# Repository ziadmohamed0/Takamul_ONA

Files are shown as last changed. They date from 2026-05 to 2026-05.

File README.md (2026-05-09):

<div align="center">

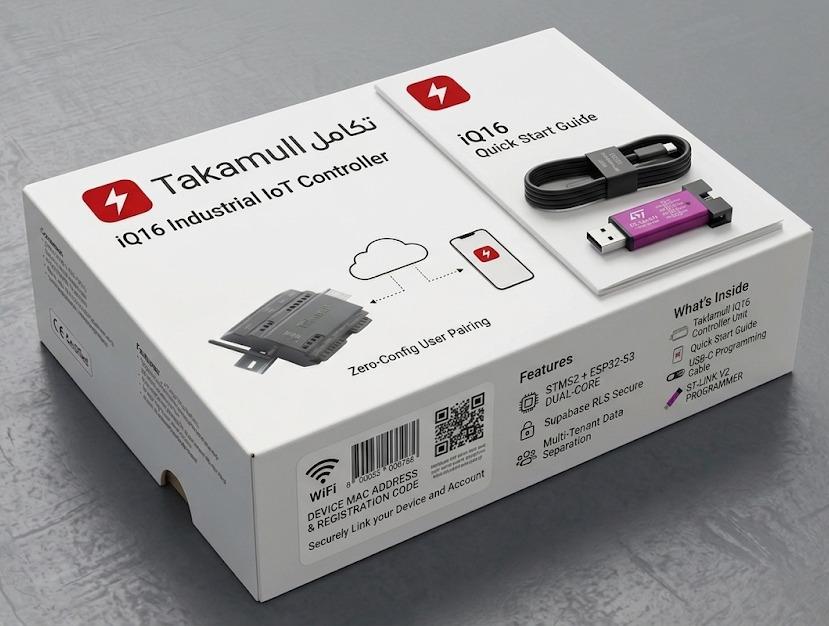
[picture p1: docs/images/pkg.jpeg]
Takamul iQ16 — Industrial IoT Controller


<br/>
<br/>

# Takamul iQ16 PLC

### Industrial IoT Controller — تكامل للحلول الذكية

<br/>








<br/>

> **Dual-core STM32F405 + ESP32-S3 · Supabase Multi-Tenant Cloud · Modbus RTU · DIN-Rail Mount**
> Designed for water treatment, flow control, and process automation in harsh industrial environments — engineered in Egypt 🇪🇬

</div>

---

## Table of Contents

- [Overview](#overview)
- [Key Features](#key-features)
- [System Architecture](#system-architecture)
- [Hardware](#hardware)
  - [PCB](#pcb--ona_hard)
  - [Mechanical Enclosure — V1](#mechanical-enclosure--v1)
  - [Mechanical Enclosure — V2](#mechanical-enclosure--v2)
- [Firmware](#firmware)
- [Cloud & Connectivity](#cloud--connectivity)
- [Repository Structure](#repository-structure)
- [Getting Started](#getting-started)
- [Supported Instruments](#supported-instruments)

---

## Overview

The **Takamul iQ16** is a compact, DIN-rail mounted industrial PLC built for real-world process automation. It pairs a **STM32F405RGT6** real-time controller — handling deterministic Modbus RTU field communication — with an **ESP32-S3** managing Wi-Fi, MQTT, and secure cloud telemetry via **Supabase Row-Level Security**.

Every unit ships ready to deploy: scan the MAC QR code on the box, link it to your account, and the device self-configures with zero manual setup.

**Built for:**
- Water treatment & desalination plants
- Flow metering systems (Endress+Hauser Promag P300)
- Multi-parameter water quality monitoring (TDS, pressure, temperature, differential)
- VFD pump control automation

---

## Key Features

| | Feature | Detail |
|---|---|---|
| ⚙️ | **Dual-Core Processing** | STM32F405RGT6 (real-time control) + ESP32-S3 (connectivity) |
| 📡 | **Field Protocols** | Modbus RTU × 2 ports (RS-485), bridged to cloud via MQTT |
| 🌊 | **Sensor Inputs** | Flow · Pressure · TDS · Temperature · Differential (5 channels) |
| ⚡ | **Actuator Outputs** | VFD Control × 2 (Variable Frequency Drive) |
| 🔋 | **Power Supply** | 12–24V DC wide-range input, onboard LM2596S regulator |
| 📶 | **Connectivity** | Wi-Fi 802.11 b/g/n, external SMA antenna, USB-C programming |
| ☁️ | **Cloud Backend** | Supabase PostgreSQL + RLS — multi-tenant, per-device data isolation |
| 🔐 | **Security** | JWT auth, RLS policies, NVS encrypted credential storage |
| 💡 | **Status Indicators** | Power · Run · Error · Comms · Wi-Fi (5 onboard LEDs) |
| 📦 | **Form Factor** | DIN-rail 35mm TS35, 3D-printable enclosure included |
| 🔌 | **Programming** | ST-LINK V2 (STM32) + USB-C ESP-IDF (ESP32) |
| 📋 | **Zero-Config** | MAC-based QR pairing — no manual IP or credential entry |

---

## System Architecture

```
┌─────────────────────────────────────────────────────────┐
│                    Field Instruments                     │
│  [Flow Meter]  [Pressure]  [TDS]  [Temp]  [Diff]       │
└──────────────────────┬──────────────────────────────────┘
                       │ Modbus RTU (RS-485)
              ┌────────▼────────┐
              │   STM32F405     │  ← Real-time deterministic control
              │  Modbus Master  │  ← VFD pump output control
              │  FreeRTOS       │
              └────────┬────────┘
                       │ UART (115200 baud)
              ┌────────▼────────┐
              │    ESP32-S3     │  ← Wi-Fi / MQTT / Cloud
              │  WifiManager    │
              │  SupabaseClient │──────────► Supabase Cloud
              │  MqttManager    │              (PostgreSQL + RLS)
              │  TelemetryMgr   │
              │  WebServer      │──────────► Local Config Portal
              │  NVSManager     │
              └─────────────────┘
```

---

## Hardware

### PCB — `ONA_HARD/`

The iQ16 PCB is a **4-layer board** designed in KiCad 7. The stackup separates power planes from signal layers to ensure clean analog sensor readings alongside noisy RS-485 and switching regulator circuits.

| Spec | Value |
|---|---|
| Layers | 4 (F.Cu · In1.Cu · In2.Cu · B.Cu) |
| MCUs | STM32F405RGT6 + ESP32-S3 module |
| Power | LM2596S buck converter, 220µF/35V + 100µF/50V bulk caps |
| RS-485 | Dual Modbus ports (ModBus 1: A/B, ModBus 2: Y/Z) |
| Programming | USB-C (ESP32) + ST-Link header (STM32) |
| Mounting | 4× M3 corner holes for DIN-rail clip assembly |
| Design tool | KiCad 7 |
| Fabrication | Gerber + drill files ready (JLCPCB / PCBWay) |

<table>
  <tr>
    <td align="center" width="50%">
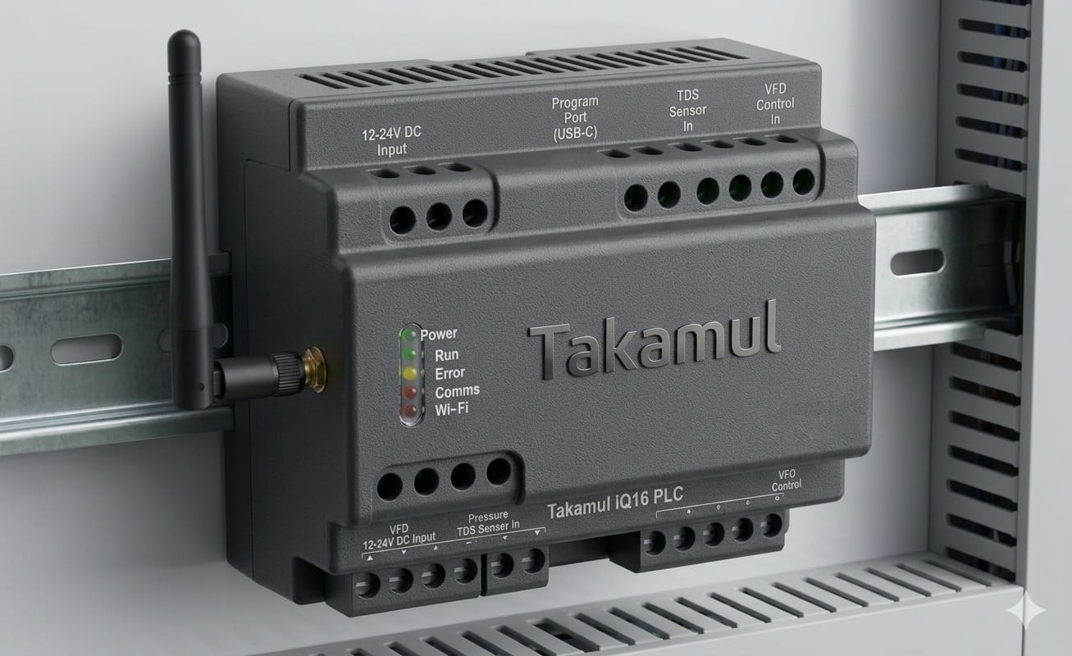
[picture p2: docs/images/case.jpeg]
iQ16 mounted on DIN rail
      
      <br/><sub><b>iQ16 — DIN-Rail Mounted</b></sub>
    </td>
    <td align="center" width="50%">
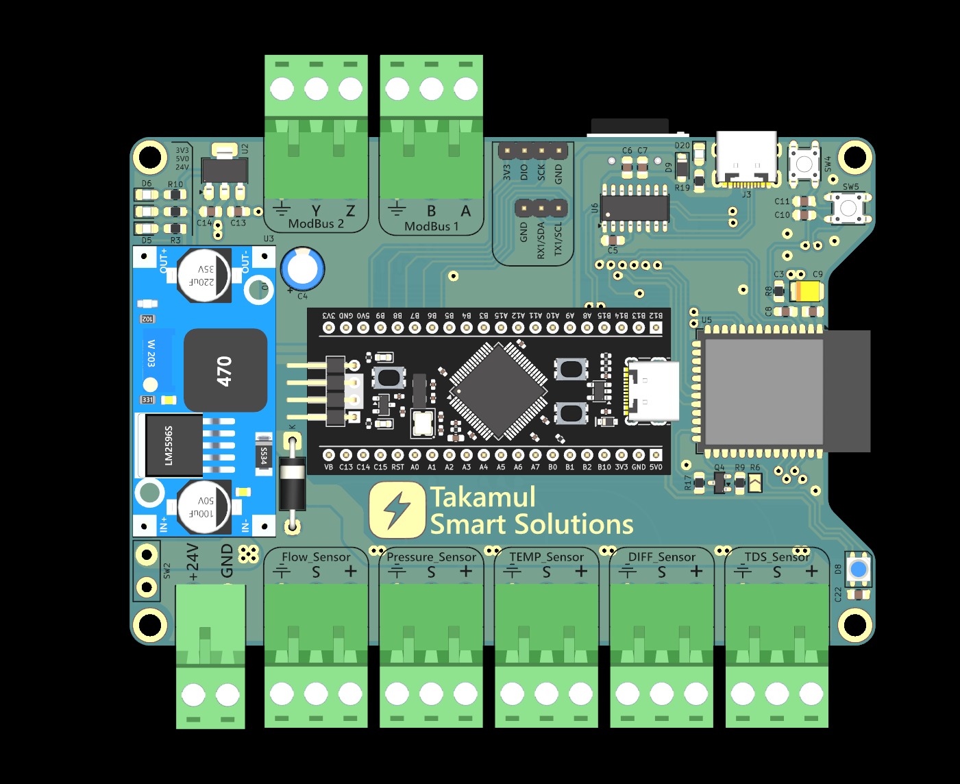
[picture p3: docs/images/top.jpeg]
PCB Top View
      
      <br/><sub><b>PCB — Top View (3D Render)</b></sub>
    </td>
  </tr>
  <tr>
    <td align="center" width="50%">
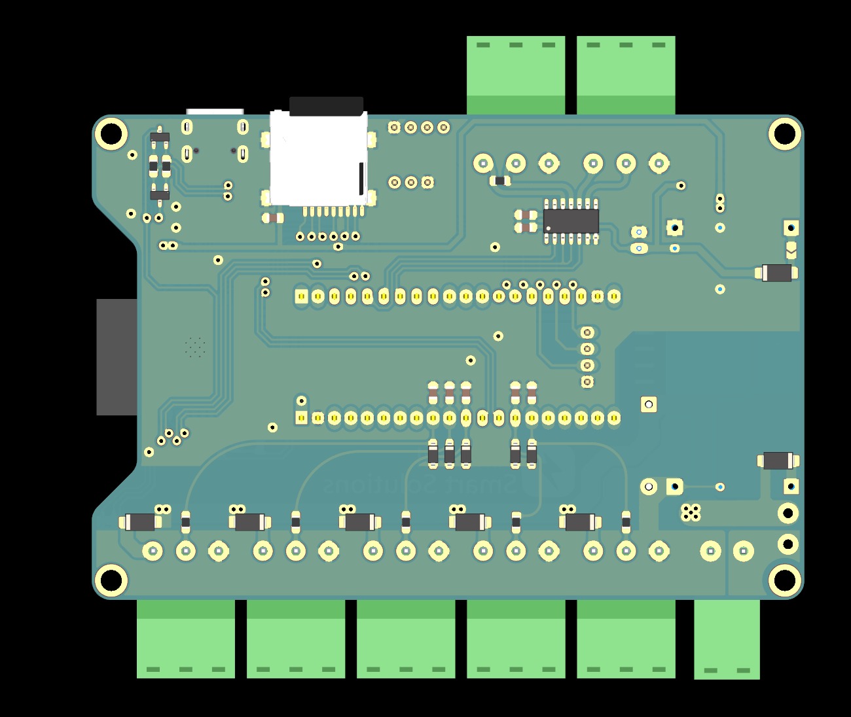
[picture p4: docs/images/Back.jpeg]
PCB Back View
      
      <br/><sub><b>PCB — Back View (3D Render)</b></sub>
    </td>
    <td align="center" width="50%">
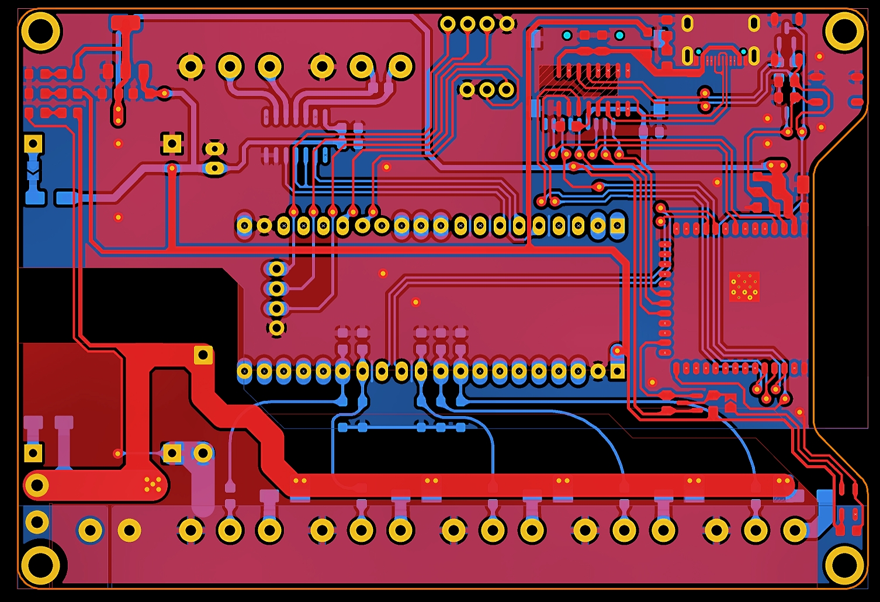
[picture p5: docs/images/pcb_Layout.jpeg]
PCB Layout
      
      <br/><sub><b>PCB — KiCad Layout (All Copper Layers)</b></sub>
    </td>
  </tr>
</table>

---

### Mechanical Enclosure — V1

First-generation 3D-printable enclosure. A 4-part snap-fit design tailored for DIN-rail deployment in standard control cabinets.

**Parts:** `Body` · `Face cover` · `Back cover` · `Head cover`

<table>
  <tr>
    <td align="center" width="50%">
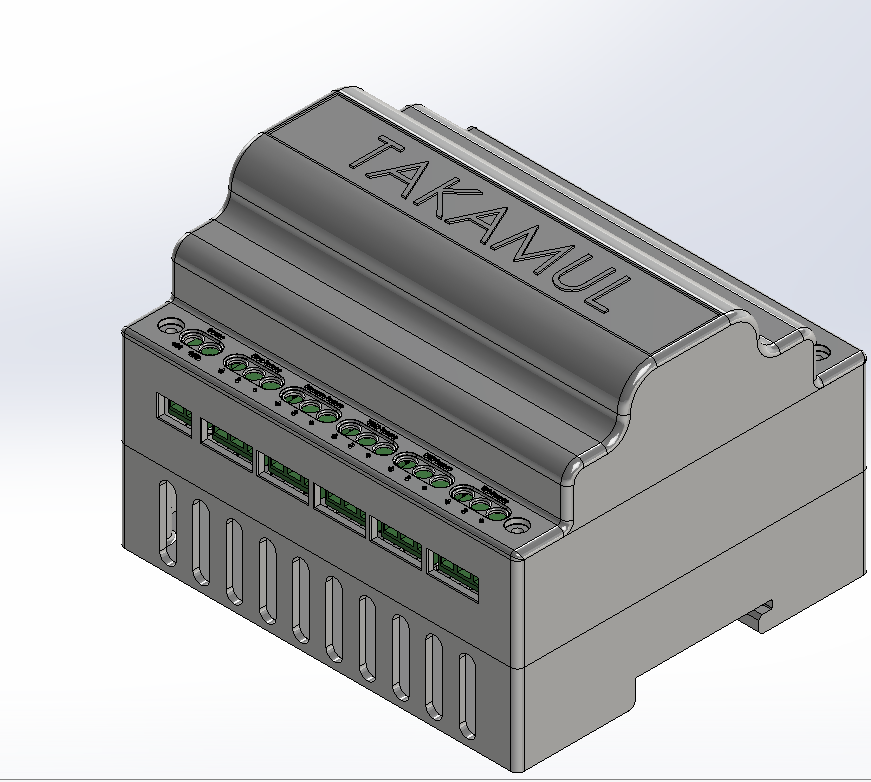
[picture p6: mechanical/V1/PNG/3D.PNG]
V1 3D View
      
      <br/><sub><b>V1 — Full Assembly (3D View)</b></sub>
    </td>
    <td align="center" width="50%">
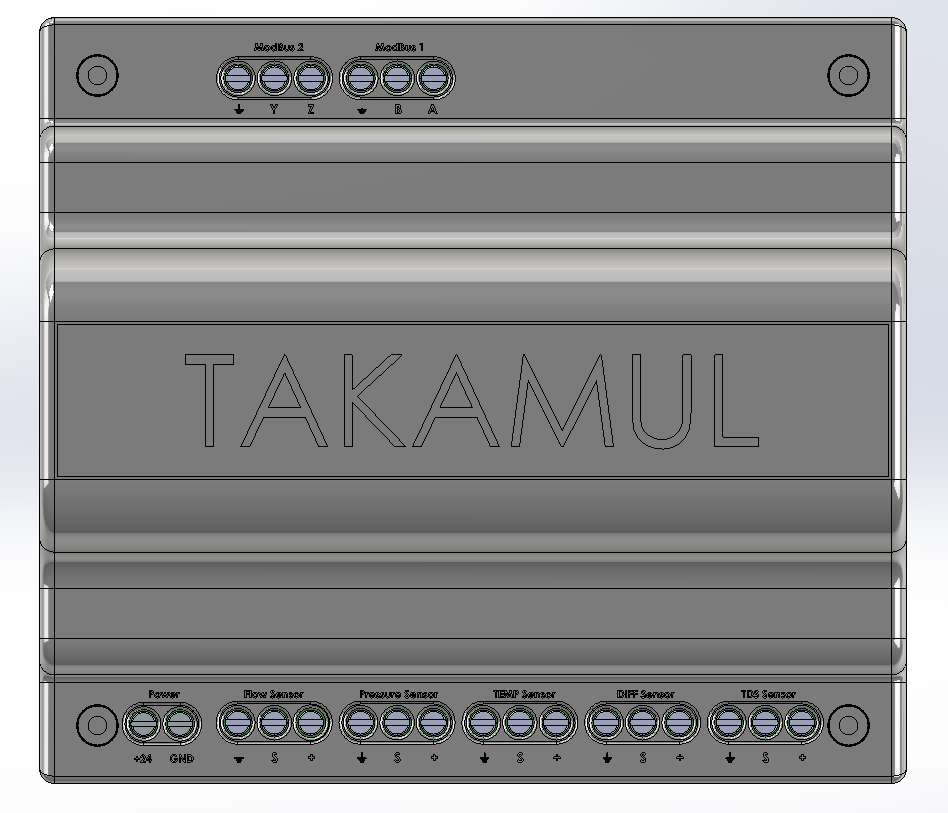
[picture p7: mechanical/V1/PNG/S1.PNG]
V1 Section 1
      
      <br/><sub><b>V1 — Front Panel View</b></sub>
    </td>
  </tr>
  <tr>
    <td align="center" width="50%">
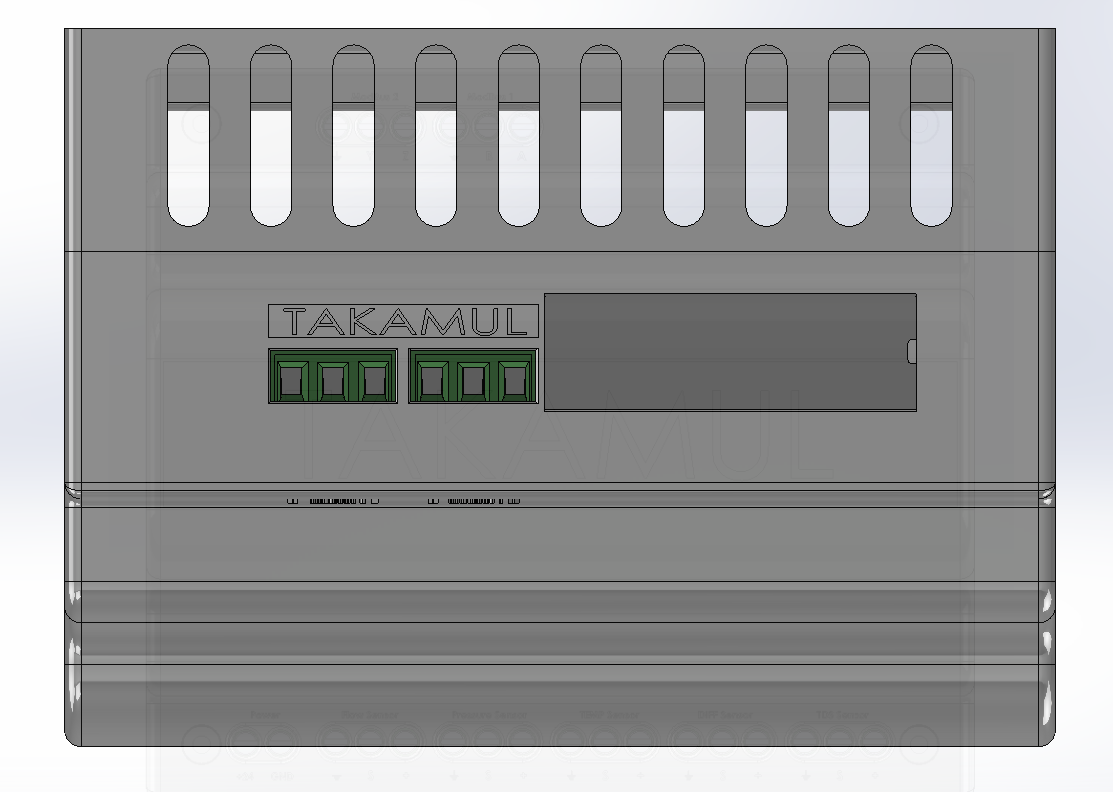
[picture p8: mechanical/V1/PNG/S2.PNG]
V1 Section 2
      
      <br/><sub><b>V1 — Side Profile</b></sub>
    </td>
    <td align="center" width="50%">
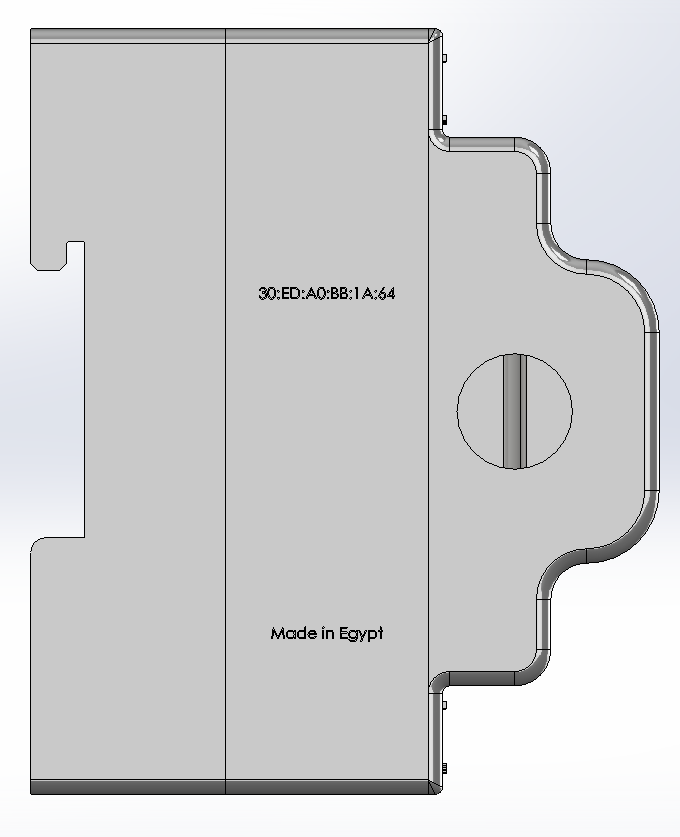
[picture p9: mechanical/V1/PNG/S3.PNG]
V1 Section 3
      
      <br/><sub><b>V1 — Internal Layout</b></sub>
    </td>
  </tr>
</table>

All V1 files are in `mechanical/V1/` — CAD source (`.SLDPRT` / `.SLDASM`) and print-ready STLs.

---

### Mechanical Enclosure — V2

Second-generation enclosure with improved cable management, refined connector cutouts, and a modular split body for easier PCB insertion and field service.

**Parts:** `Body` · `Face` · `Back` · `Part1348` (DIN clip assembly)

<table>
  <tr>
    <td align="center" width="50%">
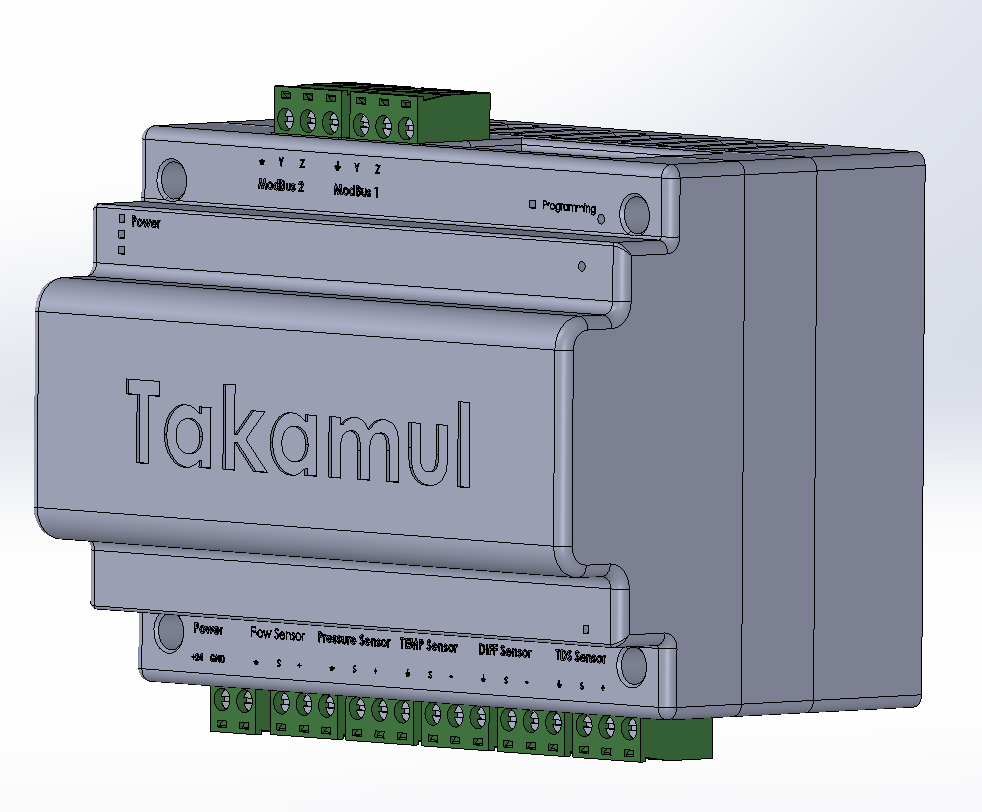
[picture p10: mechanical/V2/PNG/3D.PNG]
V2 3D View
      
      <br/><sub><b>V2 — Full Assembly (3D View)</b></sub>
    </td>
    <td align="center" width="50%">
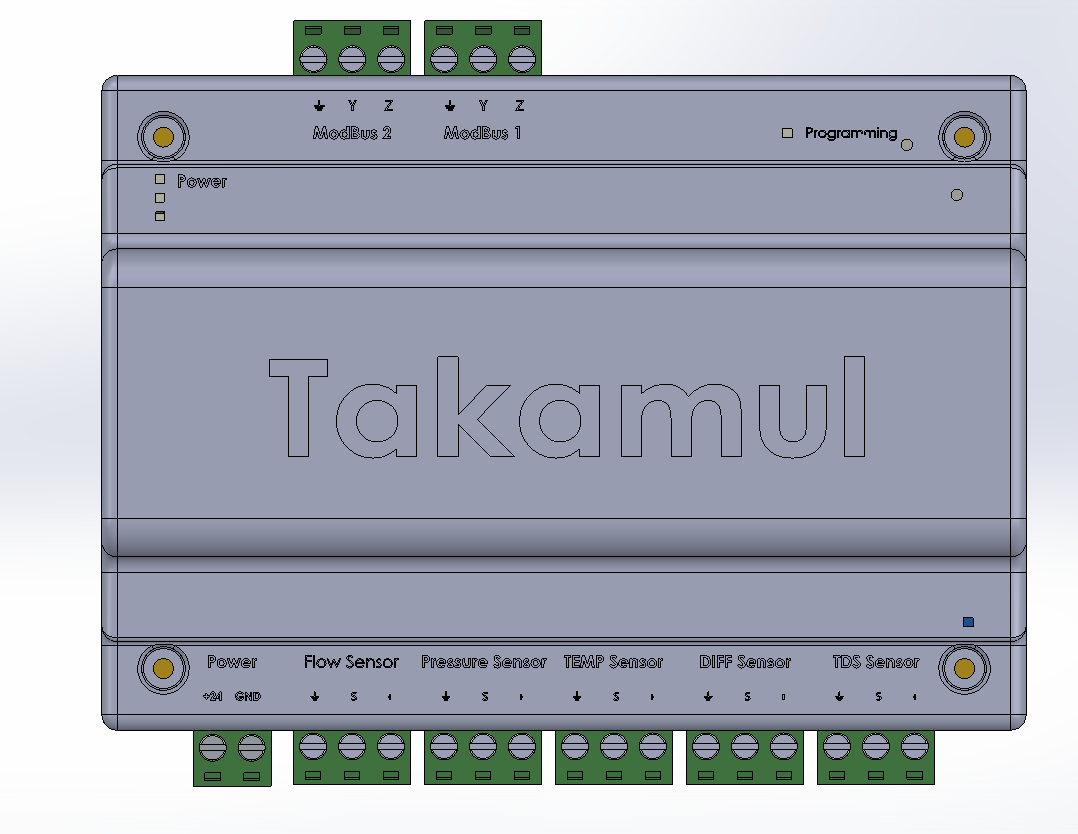
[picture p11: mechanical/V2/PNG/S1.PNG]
V2 Section 1
      
      <br/><sub><b>V2 — Front Panel View</b></sub>
    </td>
  </tr>
  <tr>
    <td align="center" width="50%">
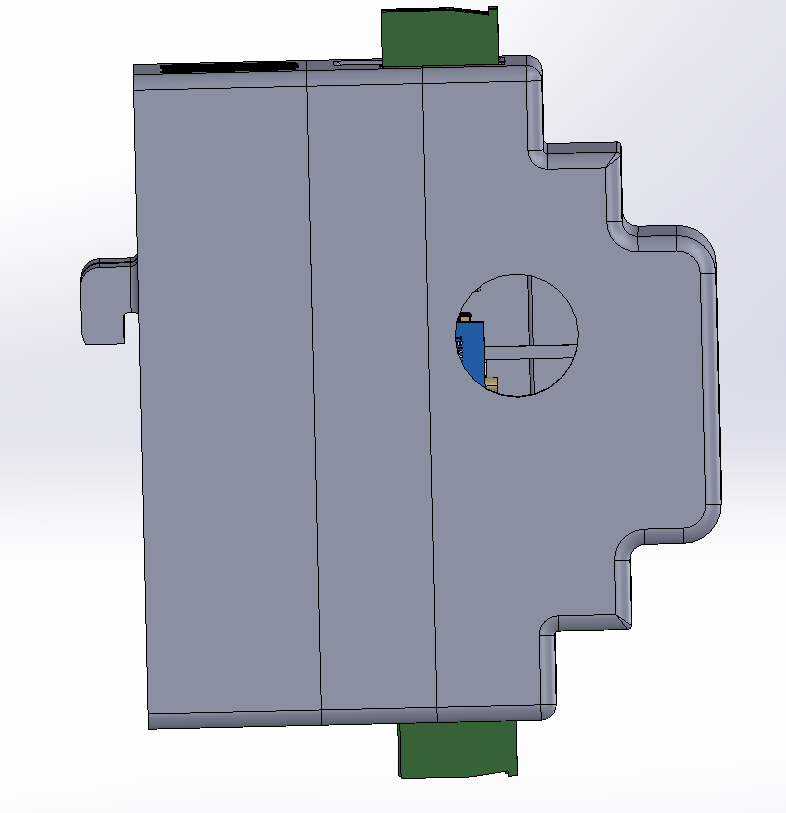
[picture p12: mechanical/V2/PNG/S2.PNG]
V2 Section 2
      
      <br/><sub><b>V2 — Side Profile</b></sub>
    </td>
    <td align="center" width="50%">
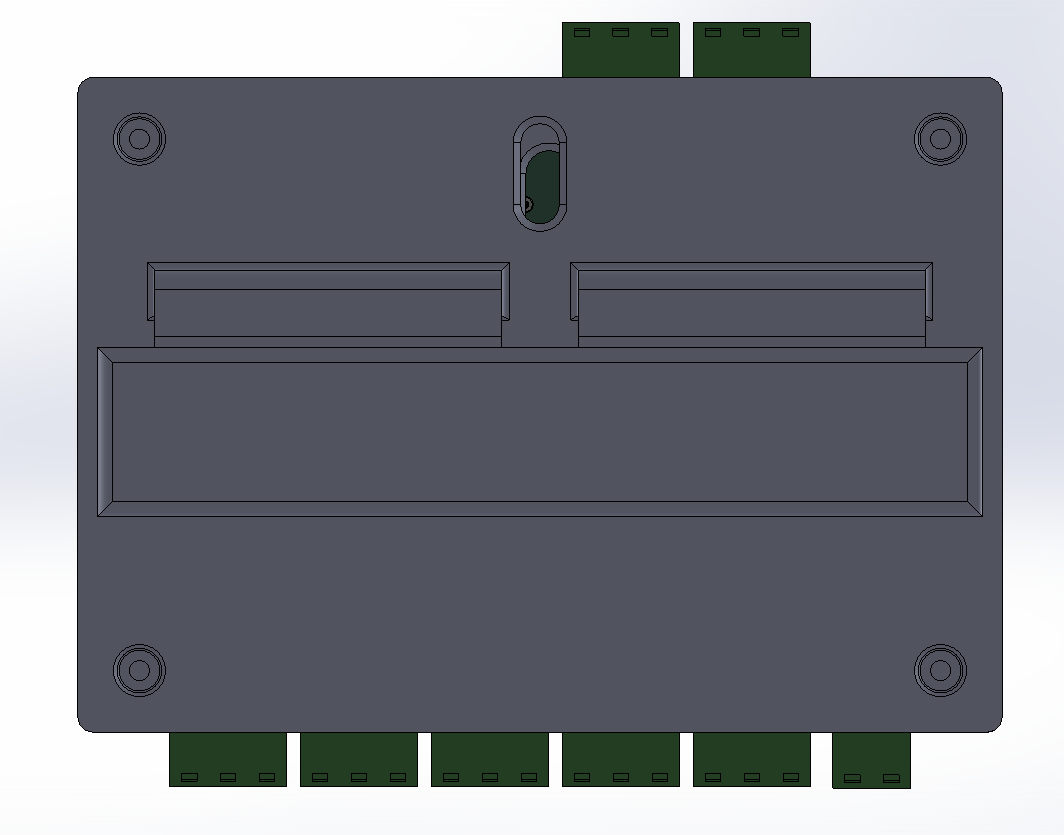
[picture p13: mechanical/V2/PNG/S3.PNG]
V2 Section 3
      
      <br/><sub><b>V2 — Rear Connector Cutouts</b></sub>
    </td>
  </tr>
  <tr>
    <td align="center" colspan="2">
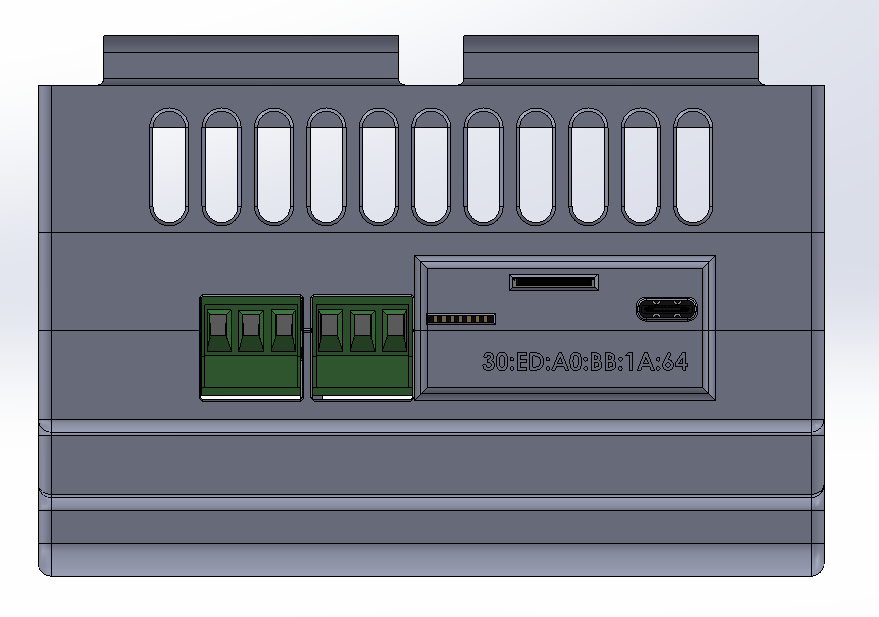
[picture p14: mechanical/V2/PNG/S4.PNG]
V2 Section 4
      
      <br/><sub><b>V2 — Exploded View / DIN Clip Detail</b></sub>
    </td>
  </tr>
</table>

All V2 files are in `mechanical/V2/` — CAD source and print-ready STLs.

> **Production-ready STL + OBJ** files (the version shipped with the product) are in `mechanical/sample/cad_v2/`. These include every printable part: `assembly`, `base`, `front_lid`, `top_lid`, `top_connectors`, `bottom_connectors`, `din_clip`, `wifi_module`, `antenna`, `standoff`, `screw_m3x8`.

---

## Firmware

### ESP32-S3 — `ONA_Software/software_v1/` (ESP-IDF v5)

The ESP32 owns all network and cloud operations, acting as a transparent bridge between the STM32 field data and the Supabase backend.

```
Takamul:: namespace
│
├── NVSManager        Flash-backed credential & config storage
├── WifiManager       Auto-connect, reconnect, provisioning fallback
├── SupabaseClient    HTTPS REST client — insert/query with JWT RLS auth
├── TelemetryManager  Periodic sensor data batching & upload
├── MqttManager       Real-time bidirectional command channel
├── UartBridge        UART2 ↔ STM32 framing & protocol (GPIO 16/17)
├── WebServer         Local HTTP config portal for Zero-Config pairing
├── OtaManager        OTA firmware update over HTTPS
└── SleepManager      Deep-sleep power management
```

**Configuring credentials** (via `idf.py menuconfig → Takamul Config`):

```
CONFIG_TAKAMUL_SUPABASE_URL   → your Supabase project URL
CONFIG_TAKAMUL_SUPABASE_KEY   → your anon/service role key
```

### STM32F405 — `ONA_Software/tests/modbus_v2/` (STM32CubeIDE)

Runs a deterministic FreeRTOS Modbus RTU master stack over RS-485. Polls all field instruments on configurable scan cycles and pushes structured telemetry frames to the ESP32 over UART.

### Modbus Mapping — `ONA_Software/tests/modbus_mapping_controll/`

STM32 firmware variant with full register mapping and VFD control logic — maps physical Modbus registers from flow meters, TDS analyzers, and pressure transmitters to structured data objects sent upstream.

---

## Cloud & Connectivity

| Layer | Technology | Purpose |
|---|---|---|
| **Database** | Supabase PostgreSQL | Persistent sensor telemetry & device registry |
| **Security** | Row-Level Security (RLS) | Per-device data isolation, multi-tenant safe |
| **Auth** | JWT tokens | Device identity tied to MAC address |
| **Real-time** | Supabase Realtime | Live dashboard subscriptions |
| **Commands** | MQTT pub/sub | Low-latency actuator control (VFD setpoints) |
| **Local config** | HTTP Web Server | Zero-Config Wi-Fi & account pairing |
| **Pairing** | QR code on box | MAC address → account link, no manual entry |
| **OTA** | HTTPS OTA | Remote firmware updates for ESP32 |

---

## Repository Structure

```
Takamul_ONA/
│
├── ONA_HARD/                          # Hardware design files
│   ├── STM32 & ESP32.kicad_pro       # KiCad 7 project
│   ├── STM32 & ESP32.kicad_sch       # Schematic
│   ├── STM32 & ESP32.kicad_pcb       # PCB layout
│   ├── BOM.xlsx                       # Bill of Materials
│   ├── STM32 & ESP32.pdf             # Schematic PDF export
│   ├── STEP File.step                 # Full assembly STEP
│   ├── top.jpeg / Back.jpeg          # PCB 3D renders
│   └── pcb_Layout.jpeg               # KiCad layout screenshot
│
├── ONA_Software/
│   ├── software_v1/esp32s3_project/  # ESP32-S3 firmware (ESP-IDF v5)
│   │   └── main/
│   │       ├── main.cpp / main.h
│   │       ├── src/
│   │       │   ├── WifiManager.cpp
│   │       │   ├── SupabaseClient.cpp
│   │       │   ├── TelemetryManager.cpp
│   │       │   ├── UartBridge.cpp
│   │       │   ├── WebServer.cpp
│   │       │   ├── MqttManager.cpp
│   │       │   ├── NVSManager.cpp
│   │       │   ├── OtaManager.cpp
│   │       │   └── SleepManager.cpp
│   │       └── inc/                  # Corresponding headers
│   │
│   ├── tests/
│   │   ├── modbus_v2/               # STM32F405 Modbus RTU stack (FreeRTOS)
│   │   ├── modbus_mapping_controll/ # Register mapping & VFD control logic
│   │   ├── STM32_Main/              # STM32F401 base firmware tests
│   │   ├── TestModbus/              # Modbus protocol unit tests
│   │   ├── stm32_master/            # STM32F103 Modbus master prototype
│   │   ├── main_esp32/              # ESP32 (original) integration tests
│   │   └── test_db/                 # ESP32 Supabase integration tests
│   │
│   └── data_sheets/                 # Instrument Modbus documentation
│       ├── Promag_P300_modbus_map.pdf
│       └── CM44x_modbus_map.pdf
│
├── mechanical/
│   ├── V1/                          # Enclosure V1 (SolidWorks + STL)
│   │   ├── CAD/                     # .SLDPRT source files
│   │   ├── STL/                     # Print-ready STL files
│   │   └── PNG/                     # 3D renders (3D, S1, S2, S3)
│   │
│   ├── V2/                          # Enclosure V2 (SolidWorks + STL)
│   │   ├── CAD/                     # .SLDPRT source files
│   │   ├── STL/                     # Print-ready STL files
│   │   └── PNG/                     # 3D renders (3D, S1, S2, S3, S4)
│   │
│   └── sample/                      # Production-ready assets
│       ├── cad_v2/                  # Final STL + OBJ (all parts)
│       ├── docs/
│       │   ├── bom_v2.csv
│       │   └── takamul_iq16_drawing_pack.pdf
│       ├── case.jpeg                # Mounted enclosure photo
│       └── pkg.jpeg                 # Product packaging render
│
└── docs/
    └── images/                      # README assets
```

---

## Getting Started

### What's in the Box

- Takamul iQ16 Controller Unit
- Quick Start Guide
- USB-C Programming Cable
- ST-LINK V2 Programmer

### Prerequisites

| Tool | Purpose | Link |
|---|---|---|
| ESP-IDF v5 | ESP32-S3 firmware build | [docs.espressif.com](https://docs.espressif.com/projects/esp-idf/en/latest/) |
| STM32CubeIDE | STM32 firmware build & flash | [st.com](https://www.st.com/en/development-tools/stm32cubeide.html) |
| KiCad 7 | PCB schematic & layout | [kicad.org](https://www.kicad.org) |
| ST-LINK V2 | STM32 programmer (included) | — |

### Flash ESP32 Firmware

```bash
cd ONA_Software/software_v1/esp32s3_project
idf.py set-target esp32s3
idf.py menuconfig        # Takamul Config → set Supabase URL & key
idf.py build flash monitor
```

### Flash STM32 Firmware

```bash
# Open in STM32CubeIDE
File → Open Projects from File System → ONA_Software/tests/modbus_v2/

# Build & flash via ST-LINK V2
Project → Build (Ctrl+B)
Run → Debug (connects via ST-LINK header)
```

### Open PCB in KiCad

```bash
kicad ONA_HARD/
# Open "STM32 & ESP32.kicad_pro" → Schematic Editor or PCB Editor
```

### Print the Enclosure (V2 — Production)

All production STL files are in `mechanical/sample/cad_v2/`. Recommended print order:

1. `base.stl` — main enclosure body
2. `din_clip.stl` — DIN-rail clip
3. `front_lid.stl` — front panel
4. `top_lid.stl` — top cover
5. `top_connectors.stl` + `bottom_connectors.stl` — terminal cutout panels
6. `standoff.stl` × 4 — PCB standoffs
7. `wifi_module.stl` — ESP32 module retainer
8. `antenna.stl` — SMA antenna bracket

> **Recommended settings:** PLA or PETG, 0.2mm layer height, 4 perimeters, 30% infill.

---

## Supported Instruments

| Instrument | Protocol | Datasheet |
|---|---|---|
| Endress+Hauser Promag P300 | Modbus RTU | `ONA_Software/data_sheets/Promag_P300_modbus_map.pdf` |
| Endress+Hauser Liquiline CM44x | Modbus RTU | `ONA_Software/data_sheets/CM44x_modbus_map.pdf` |
| Generic TDS Sensor | Analog / RS-485 | — |
| Generic Pressure Transmitter | 4–20 mA | — |
| Generic Temperature Sensor | Analog | — |

---

<div align="center">

<br/>

**Takamul Smart Solutions — تكامل للحلول الذكية**

*Industrial IoT, engineered in Egypt 🇪🇬*

<br/>

</div>

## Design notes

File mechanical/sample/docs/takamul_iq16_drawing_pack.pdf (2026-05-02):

# Takamul IQ16 PLC - Reverse Engineered Package

Reference-based 3D/STL/OBJ package derived from supplied images

### Package contents:

- STL and OBJ files for base, front lid, top vent lid, antenna, DIN clip, screw, standoff, full assembly

### - PDF drawing pack and source SCAD - Included reference images used for reverse engineering

### Primary dimensions used:

160 mm width, 115 mm height, 62 mm depth, 2.5 mm wall thickness,
140 mm top module width, 95 mm body span noted in sheet, M3x8 screws, ABS / metal material note.

### Important note:

Several internal/detail dimensions are not fully readable in the supplied sheet.
Those areas were reconstructed as manufacturable approximations while preserving the visible external envelope and named features.

# Orthographic Control Dimensions

External envelope and major visible interface groups

Takamul

160 mm

115 mm

55 mm 20 mm 55 mm
FRONT VIEW

62 mm

115 mm

SIDE VIEW

140 mm

62 mm

TOP VIEW

# Internal Features and Assembly Notes

Reconstructed from exploded views and labels visible in the supplied sheet

Item | Count | Material/Type | Notes
Housing base | 1 | ABS-like shell | 160 x 62 x 115 mm external envelope; 2.5 mm nominal wall
Front lid | 1 | ABS-like shell | Front plate and terminal shelves
Top vent lid | 1 | ABS-like shell | Approx. 140 mm wide vent cover
Antenna | 1 | Plastic/rubber visual modelSeparate simplified external antenna
DIN rail clip | 1 | Spring metal simplified | Rear mounting clip placeholder
PCB mounting bosses | 6 | Integrated plastic | Internal posts with pilot holes
Connector bosses | 6 | Integrated plastic | Near terminal regions
Screw posts | 4 | Integrated plastic | Corner posts for enclosure fastening
Brass standoffs | 4 | Brass simplified | M3-compatible
Brass M3 x 8 screws | 4 | Metal simplified | Visual/assembly placeholders
USB-C holder | 1 | Integrated plastic | Bottom-center slot/holder region
Wi-Fi bracket/routing | 1 | Integrated plastic | Internal routing guide / bracket

Assumptions used where the sheet is incomplete: terminal-hole pitch, detailed boss spacing, DIN clip geometry, antenna boss shape, and exact cover split line. These were reconstructed to preserve the visible layout and create a workable manufacturing/printing package.

# Reference Images Included

Supplied by the user and packed inside the ZIP under /refs

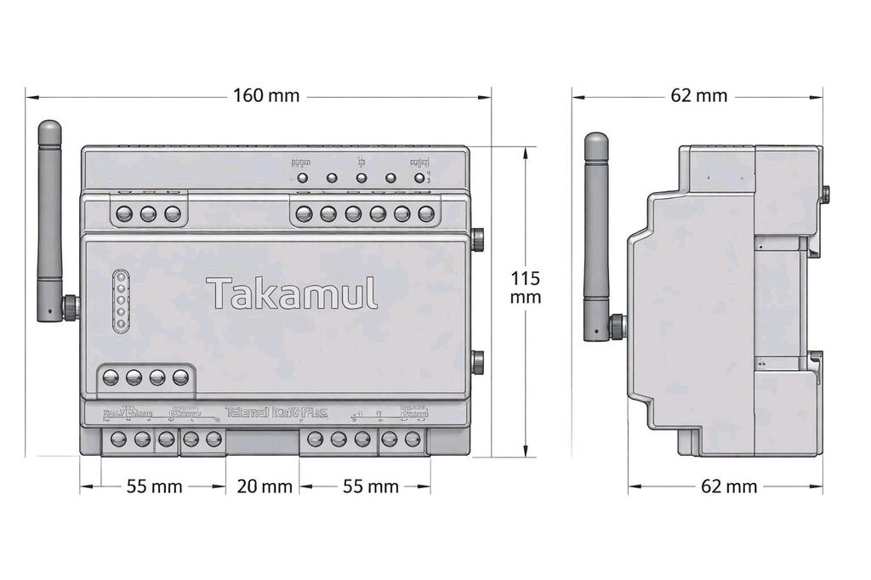
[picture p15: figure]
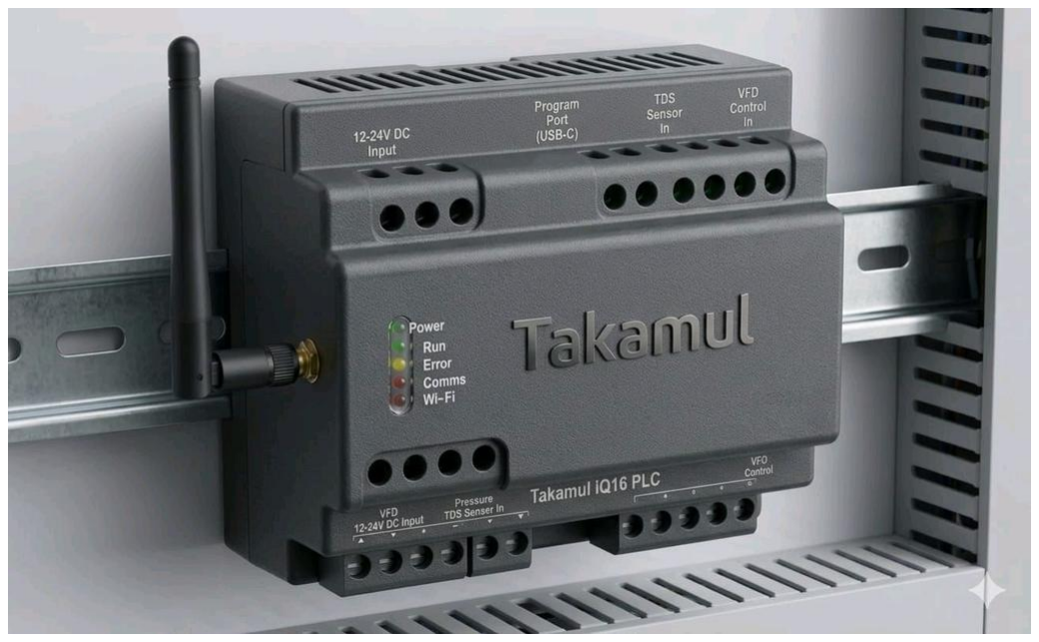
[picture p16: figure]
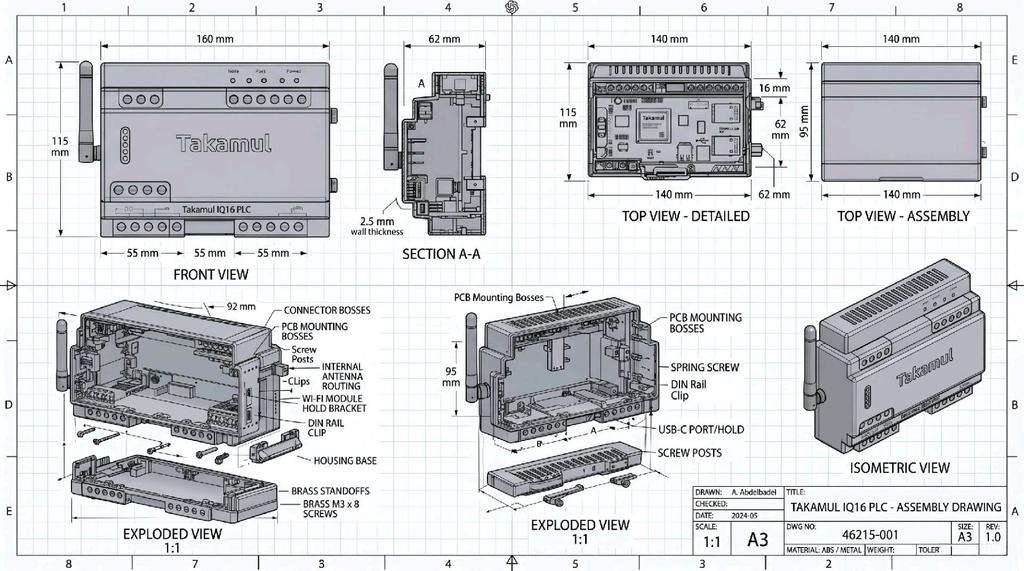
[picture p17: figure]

assembly_sheet.jpg | product_render.jpg | dimension_views.jpg

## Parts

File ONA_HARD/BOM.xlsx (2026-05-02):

Ref | Value | Footpint | Qty | Shop | Link
C14 | 22U | Capacitor_SMD:C_0805_2012Metric_Pad1.18x1.45mm_HandSolder | 1 | Makers | https://makerselectronics.com/product/multilayer-ceramic-capacitors-mlcc-smd-25v-22uf-x5r-%c2%b120-0805/
D2, D15-D19 | SS36 | Diode_SMD:D_SMA | 6 | Makers | https://makerselectronics.com/product/ss36-sma-schottky-barrier-diodes-sbd-smd-60v-single-0-7v3a-3a/
D3 | SS16 | Diode_SMD:D_SMA | 1 | Makers | https://makerselectronics.com/product/ss16-sma-schottky-barrier-diodes-sbd-smd-60v-700mv1a-1a/
D4 | P6KE27A | Diode_THT:D_DO-15_P12.70mm_Horizontal | 1 | Makers | https://makerselectronics.com/product/esd-suppressors-tvs-diodes-600w-27v-uni-directional-p6ke27a-e3-73/
D5, D6, D10 | LED_RED | LED_SMD:LED_0805_2012Metric_Pad1.15x1.40mm_HandSolder | 3 | Makers | https://makerselectronics.com/product/smd-led-0805/
D7, D11-D14 | MM1Z3V3 | Diode_SMD:D_SOD-123 | 5 | Makers | https://makerselectronics.com/product/mm1z3v3-w3-zener-diode-smd-single-3-1v3-5v-500mw-3-3v-sod-123/
D9 | 1N5819WF | Diode_SMD:D_SOD-123F | 1 | Makers | https://makerselectronics.com/product/1n5819wf-sl-40v-600mv1a-1a-smd-sod-123f-smd-schottky-barrier-diodes-sbd/
J2 | Pluggable Terminal 2P | abjad:Pluggable Terminal 2P P5.08mm | 1 | Makers | https://makerselectronics.com/product/terminal-block-kf2edgr-5-08-2p/
J3 | USB_TYPEC_12P | Connector_USB:USB_C_Receptacle_G-Switch_GT-USB-7010ASV | 1 | Makers | https://makerselectronics.com/product/smd-usb-female-connectors-type-c-16-pin/
J4-J10 | Pluggable Terminal 3P | abjad:Pluggable Terminal 3P P5.08mm | 7 | Makers | https://makerselectronics.com/product/terminal-block-kf2edgr-5-08-3p/
J11 | UART | Connector_PinHeader_2.54mm:PinHeader_1x03_P2.54mm_Vertical | 1 | Makers | https://makerselectronics.com/product/pin-headers-male-2-54mm-40-pin-straight-black-11mm/
Q2, Q3 | SS8050 | Package_TO_SOT_SMD:SOT-23 | 2 | Makers | https://makerselectronics.com/product/ss8050-y1-bipolar-transistors-bjt-smd-25v-300mw-200100ma1v-1-5a-npn-sot-23/
R3 | 4K7 | Resistor_SMD:R_0805_2012Metric_Pad1.20x1.40mm_HandSolder | 1 | Makers | https://makerselectronics.com/product/chip-resistor-smd-4-7k%cf%89-%c2%b11-0-125w-%c2%b1100ppm-%e2%84%83-0805/
R4, R5, R8, R9, R17 | 10K | Resistor_SMD:R_0805_2012Metric_Pad1.20x1.40mm_HandSolder | 5 | Makers | https://makerselectronics.com/product/chip-resistor-smd-10k%cf%89-%c2%b15-0-125w-%c2%b1100ppm-%e2%84%83-0805/
R10 | 1K2 | Resistor_SMD:R_0805_2012Metric_Pad1.20x1.40mm_HandSolder | 1 | Makers | https://makerselectronics.com/product/chip-resistor-smd-1-2k%cf%89-%c2%b15-0-125w-%c2%b1100ppm-%e2%84%83-0805/
R11 | 2K2 | Resistor_SMD:R_0805_2012Metric_Pad1.20x1.40mm_HandSolder | 1 | Makers | https://makerselectronics.com/product/chip-resistor-smd-2-2k%cf%89-%c2%b11-0-125w-%c2%b1100ppm-%e2%84%83-0805/
R12-R16, R18 | 150R | Resistor_SMD:R_0805_2012Metric_Pad1.20x1.40mm_HandSolder | 6 | Makers | https://makerselectronics.com/product/chip-resistor-smd-150%cf%89-%c2%b11-0-125w-%c2%b1100ppm-%e2%84%83-0805/
SW2 | SW_6A | abjad:SW-KCD-6A | 1 | Makers | https://makerselectronics.com/product/on-off-red-switch-3-pins-250vac-6a/
U6 | CH340C | Package_SO:SOIC-16_3.9x9.9mm_P1.27mm | 1 | Makers | https://makerselectronics.com/product/ch340c-smd-ic-transceiver-usb-2-0-2mbps-sop-16/
U3 | LM2596S DC-DC | abjad:LM2596S DC-DC Converter 3A | 1 | Makers | https://makerselectronics.com/product/lm2596hvs-dc-dc-buck-converter-3a/
U4 | STM32F401RCT6 | abjad:Black Pill STM32F401RCT6 | 1 | Makers | https://makerselectronics.com/product/stm32f401rct6-stm32-development-boa/
U5 | ESP32-S3 N16R8 | RF_Module:ESP32-S3-WROOM-1 | 1 | Uge | https://uge-one.com/product/esp32-s3-n16r8-high-performance-wifi-ble5-smd-module/
U7 | MAX491E | Package_SO:SOIC-14_3.9x8.7mm_P1.27mm | 1 | Makers | https://makerselectronics.com/product/max491esd-transceiver-2-5mbps-1-1-soic-14-rs-485-rs-422-smd-ic/
J1 | SD Card Connector | abjad:SD Card Connector GCT_MEM2075 | 1 | UGE | https://uge-one.com/product/microsd-memory-sd-card-socket-pcb-mounted/
D8 | WS2812B | LED_SMD:LED_WS2812B-Mini_PLCC4_3.5x3.5mm | 1 | UGE | https://uge-one.com/product/ws2812b-programmable-rgb-led-chip-3535-smd-package/
Q4 | BSS138 | Package_TO_SOT_SMD:SOT-23 | 1 | Ram | https://www.ram-e-shop.com/shop/smd-bss138-smd-bss138-8694
SW4, SW5 | SW | Button_Switch_SMD:SW_SPST_PTS647_Sx50 | 2 | Uge | https://uge-one.com/product/smd-mini-pushbutton-switch-4p-4-5x4-5x2-5mm/
U2 | AMS1117-3.3 | Package_TO_SOT_SMD:SOT-223-3_TabPin2 | 1 | Ram | https://www.ram-e-shop.com/shop/lt1117-3-3v-ams1117-3-3v-6628

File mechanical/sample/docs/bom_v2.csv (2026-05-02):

item | count | material | category | notes
housing_base | 1 | ABS-like shell | enclosure | 2.5mm nominal wall based on drawing sheet
front_lid | 1 | ABS-like shell | enclosure | front cover with engraved logo and I/O labels
top_vent_lid | 1 | ABS-like shell | enclosure | 140mm visible top vented cover
antenna_whip | 1 | plastic/rubber | external | left-side antenna assembly with pivot base
din_clip | 1 | spring steel simplified | mechanical | rear DIN rail mount clip
main_pcb | 1 | FR4 simplified | electronics | placeholder board with major component envelopes
wifi_module | 1 | FR4 simplified | electronics | antenna-side daughter module placeholder
top_terminal_block_group | 1 | PA66/metal simplified | electronics | power + USB-C + sensor/VFD connector zone
bottom_terminal_block_group | 1 | PA66/metal simplified | electronics | lower DI/relay/RS485 connector zone
pcb_mounting_bosses | 6 | integrated plastic | integrated feature | internal PCB supports
connector_bosses | 11 | integrated plastic | integrated feature | front connector support features
screw_posts | 4 | integrated plastic | integrated feature | enclosure fastening towers
brass_standoffs | 4 | brass simplified | hardware | M3 compatible standoffs
m3x8_screws | 4 | steel simplified | hardware | visual/assembly fasteners
led_lightpipes | 5 | clear PC simplified | optical | status indicator light guides
usb_c_support_shelf | 1 | integrated plastic | integrated feature | front programming port support
antenna_bracket | 1 | integrated plastic | integrated feature | internal RF bracket region
internal_ribs_and_shelves | 1 | set | integrated feature | added for enclosure stiffness and placement guidance

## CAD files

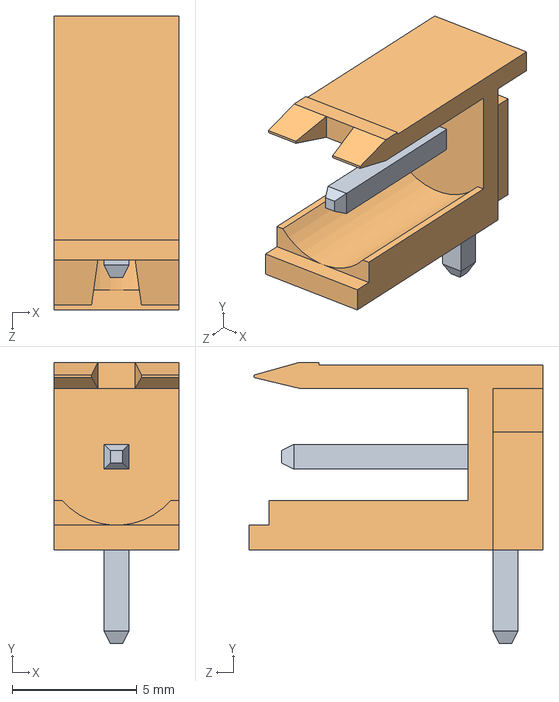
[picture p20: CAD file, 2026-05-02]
ONA_HARD/3d models/kf2edgk-pluggable-terminal-block-1.snapshot.1/Socket/1P.SLDASM
5.00 x 11.3 x 11.8 mm
Metal
Socket

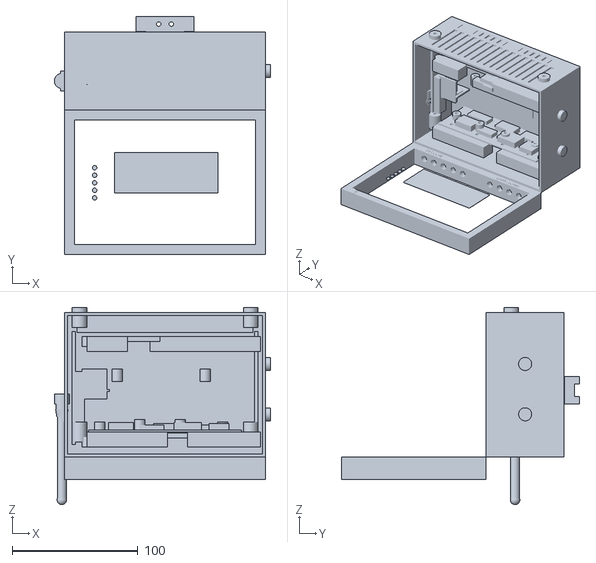
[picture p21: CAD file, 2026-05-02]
mechanical/sample/cad_v2/assembly.stl
172.0 x 189.2 x 156.8

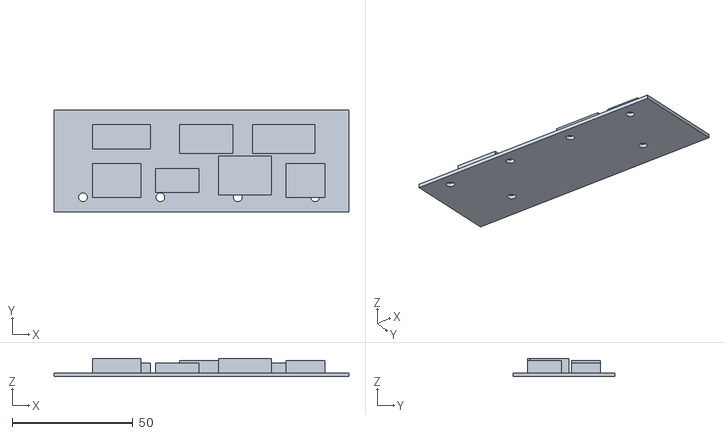
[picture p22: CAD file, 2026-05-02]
mechanical/sample/cad_v2/pcb_main.stl
122.0 x 42.0 x 7.60

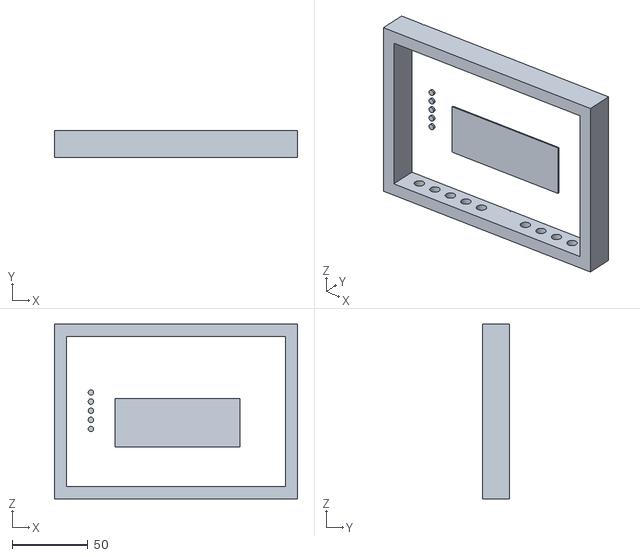
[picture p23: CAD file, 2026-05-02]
mechanical/sample/cad_v2/front_lid.stl
160.0 x 18.0 x 115.0

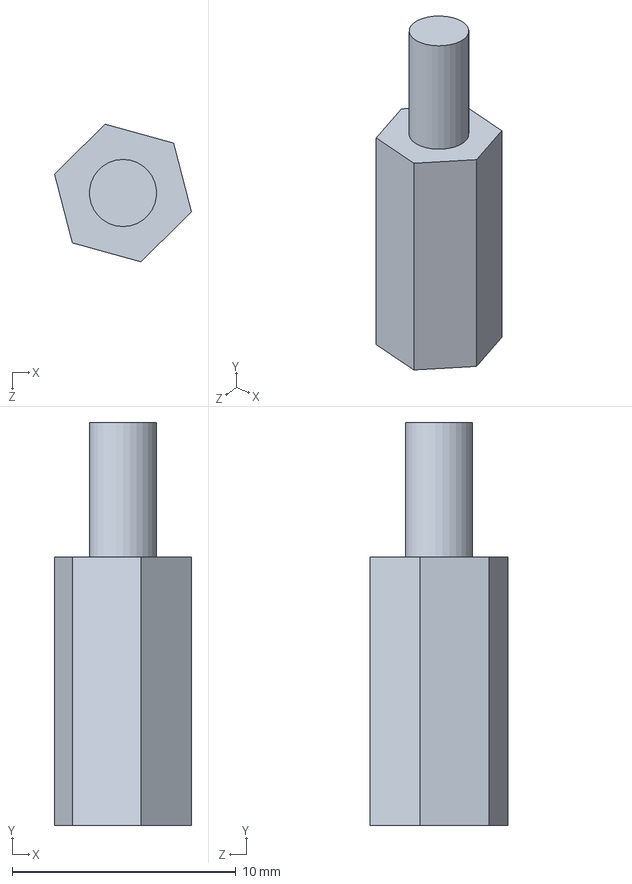
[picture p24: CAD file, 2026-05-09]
mechanical/V2/CAD/Part1348.SLDPRT
6.12 x 18.0 x 6.15 mm

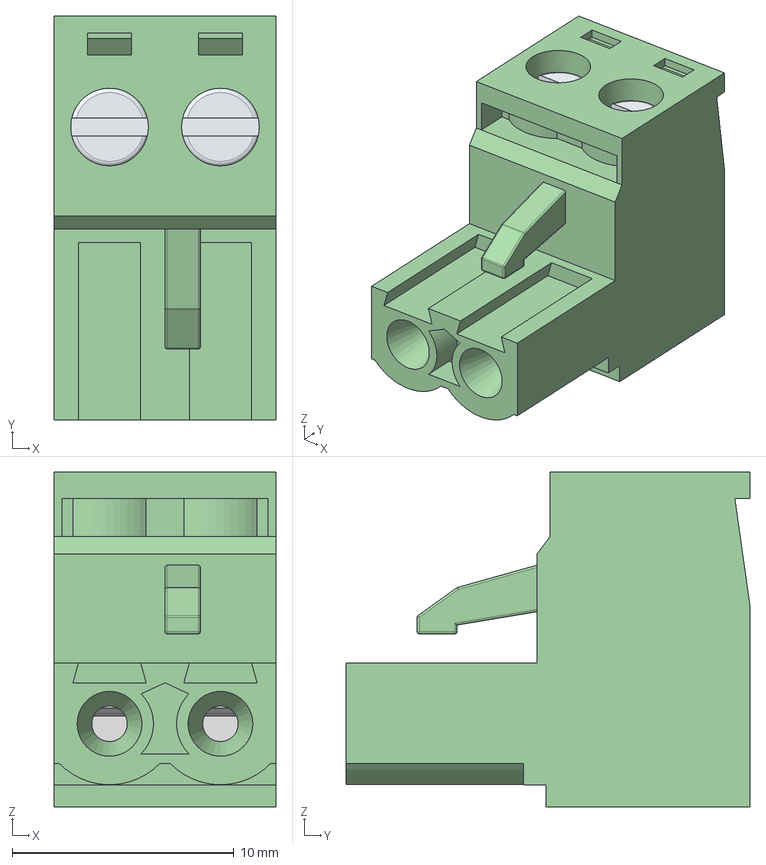
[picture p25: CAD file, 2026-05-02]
ONA_HARD/3d models/kf2edgk-pluggable-terminal-block-1.snapshot.1/Head/2P.stp
10.0 x 18.2 x 15.1 mm
6913527100xx_PIN x 2
6913527100xxCAGE x 2
6913527100xx_VIS x 2
691352710002_COFFRE

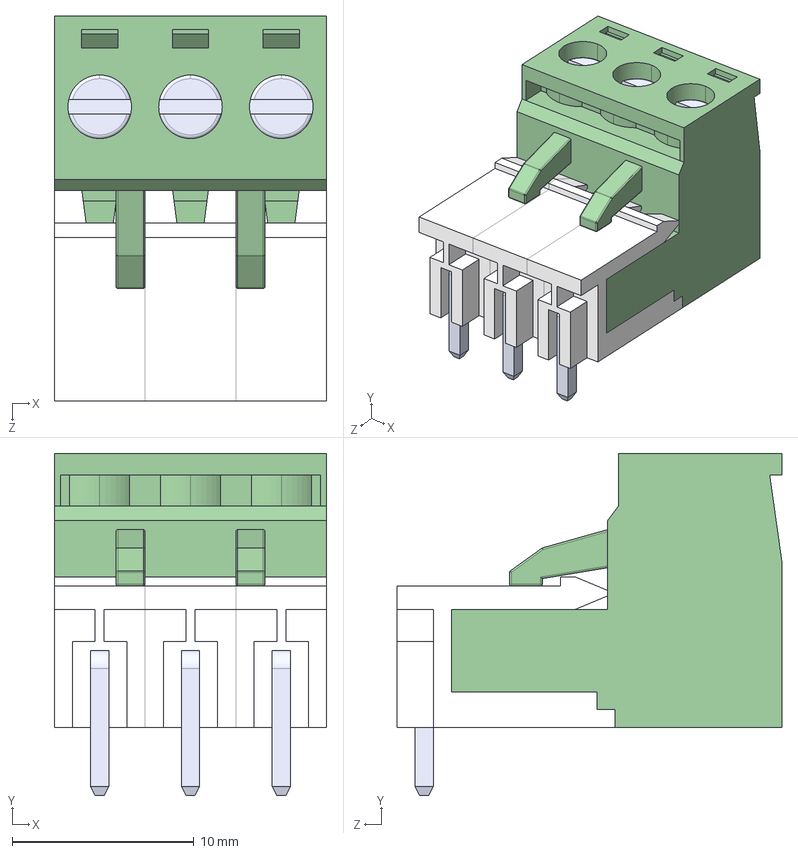
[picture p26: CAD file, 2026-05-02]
ONA_HARD/3d models/kf2edgk-pluggable-terminal-block-1.snapshot.1/STEP/3P.STEP
15.0 x 18.8 x 21.2 mm
6913527100xx_PIN.stp x 3
6913527100xxCAGE.stp x 3
6913527100xx_VIS.stp x 3
691352710003.stp
691352710003_COFFRE.stp
Metal x 3
Socket x 3

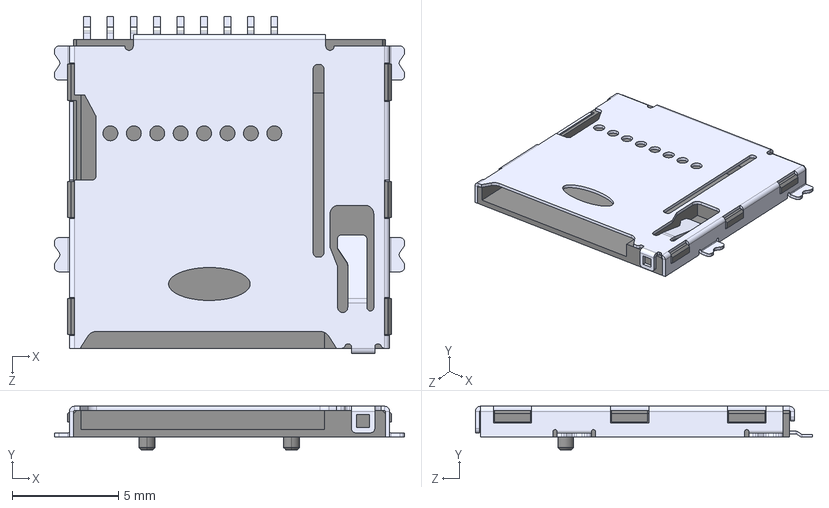
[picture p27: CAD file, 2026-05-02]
ONA_HARD/3d models/MEM2075-00-140-01-A--3DModel-STEP-56544.STEP
16.4 x 2.05 x 15.9 mm

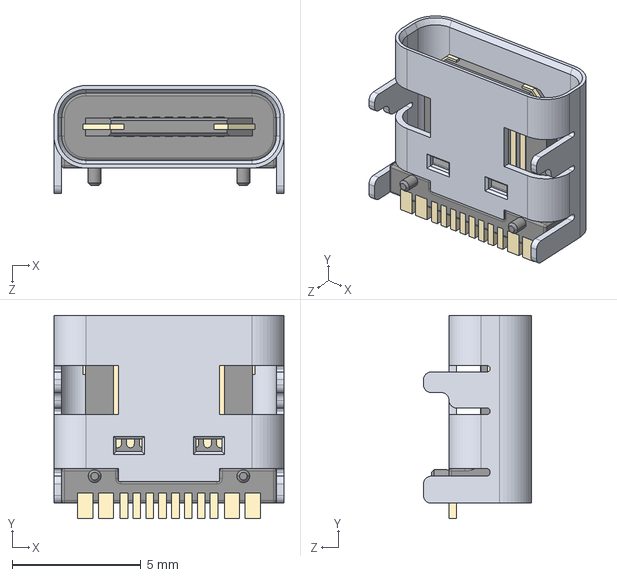
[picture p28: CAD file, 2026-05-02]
ONA_HARD/3d models/usb-type-c-port-smd-type-1.snapshot.6/USB Type C Port (SMD Type).STEP
8.94 x 7.90 x 4.20 mm

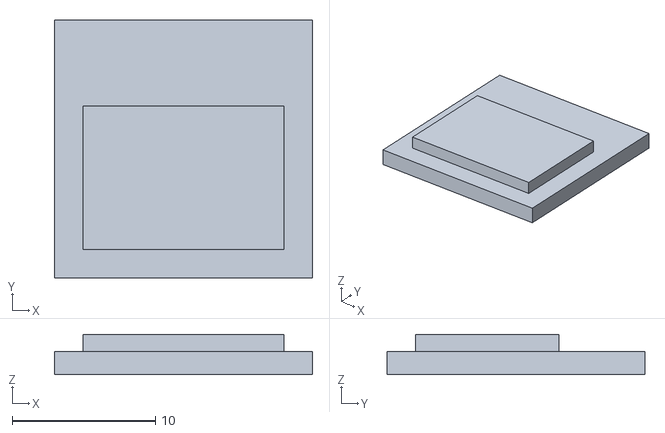
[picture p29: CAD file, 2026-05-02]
mechanical/sample/cad_v2/wifi_module.stl
18.0 x 18.0 x 2.80

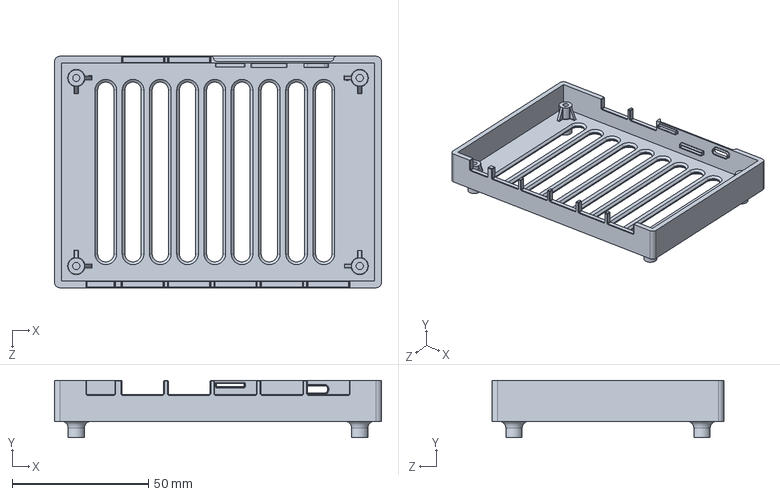
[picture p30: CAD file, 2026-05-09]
mechanical/V2/CAD/Body.SLDPRT
120.0 x 21.0 x 85.0 mm

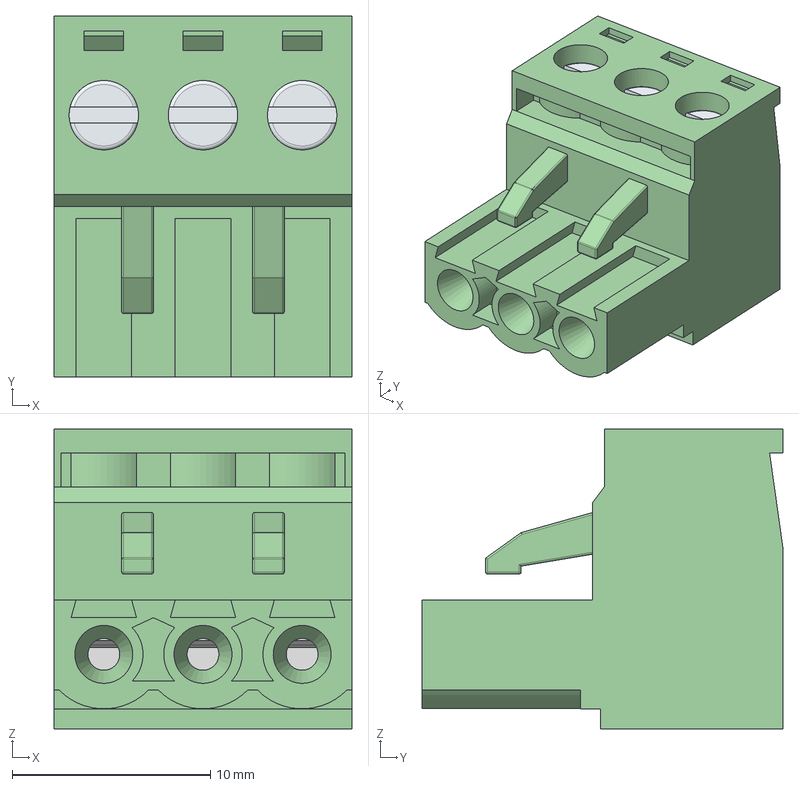
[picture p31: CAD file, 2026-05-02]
ONA_HARD/3d models/kf2edgk-pluggable-terminal-block-1.snapshot.1/Head/3P.stp
15.0 x 18.2 x 15.1 mm
6913527100xx_PIN x 3
6913527100xxCAGE x 3
6913527100xx_VIS x 3
691352710003_COFFRE

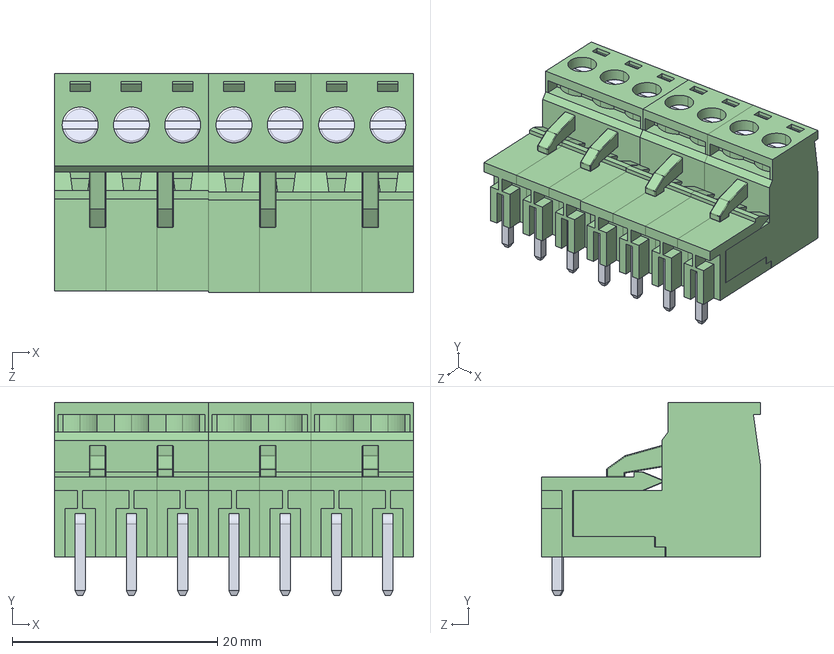
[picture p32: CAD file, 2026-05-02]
ONA_HARD/3d models/kf2edgk-pluggable-terminal-block-1.snapshot.1/STEP/7P.STEP
35.0 x 18.8 x 21.3 mm
6913527100xx_PIN.stp x 7
6913527100xxCAGE.stp x 7
6913527100xx_VIS.stp x 7
691352710003.stp
691352710003_COFFRE.stp
Metal x 7
Socket x 7
691352710002.stp x 2
691352710002_COFFRE.stp x 2

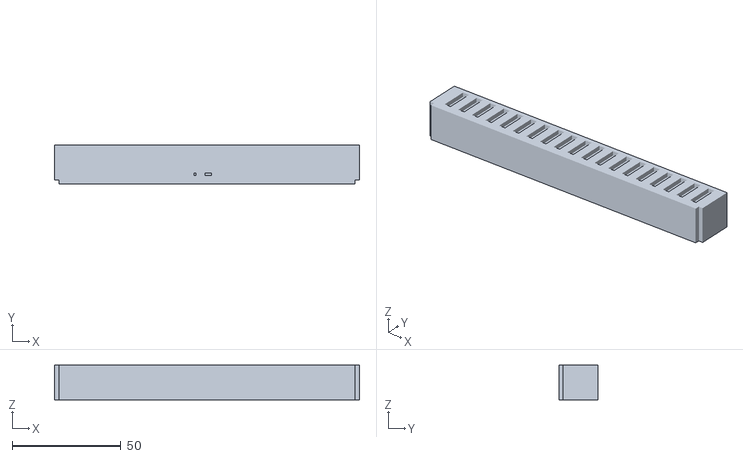
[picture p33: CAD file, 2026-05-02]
mechanical/sample/cad_v2/top_lid.stl
140.0 x 18.0 x 16.0

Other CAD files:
mechanical/V2/CAD/Back.SLDPRT
ONA_HARD/3d models/kf2edgk-pluggable-terminal-block-1.snapshot.1/STEP/4P.STEP
mechanical/sample/cad_v2/top_connectors.stl
mechanical/V2/CAD/Face.SLDPRT
ONA_HARD/3d models/kf2edgk-pluggable-terminal-block-1.snapshot.1/STEP/10P.STEP
ONA_HARD/3d models/kf2edgk-pluggable-terminal-block-1.snapshot.1/STEP/11P.STEP
ONA_HARD/3d models/kf2edgk-pluggable-terminal-block-1.snapshot.1/STEP/12P.STEP
ONA_HARD/3d models/kf2edgk-pluggable-terminal-block-1.snapshot.1/STEP/2P.STEP
ONA_HARD/3d models/kf2edgk-pluggable-terminal-block-1.snapshot.1/STEP/5P.STEP
ONA_HARD/3d models/kf2edgk-pluggable-terminal-block-1.snapshot.1/STEP/6P.STEP
ONA_HARD/3d models/kf2edgk-pluggable-terminal-block-1.snapshot.1/STEP/8P.STEP
ONA_HARD/3d models/kf2edgk-pluggable-terminal-block-1.snapshot.1/STEP/9P.STEP
ONA_HARD/3d models/usb-type-c-port-smd-type-1.snapshot.6/USB Type C Port (SMD Type).SLDPRT
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

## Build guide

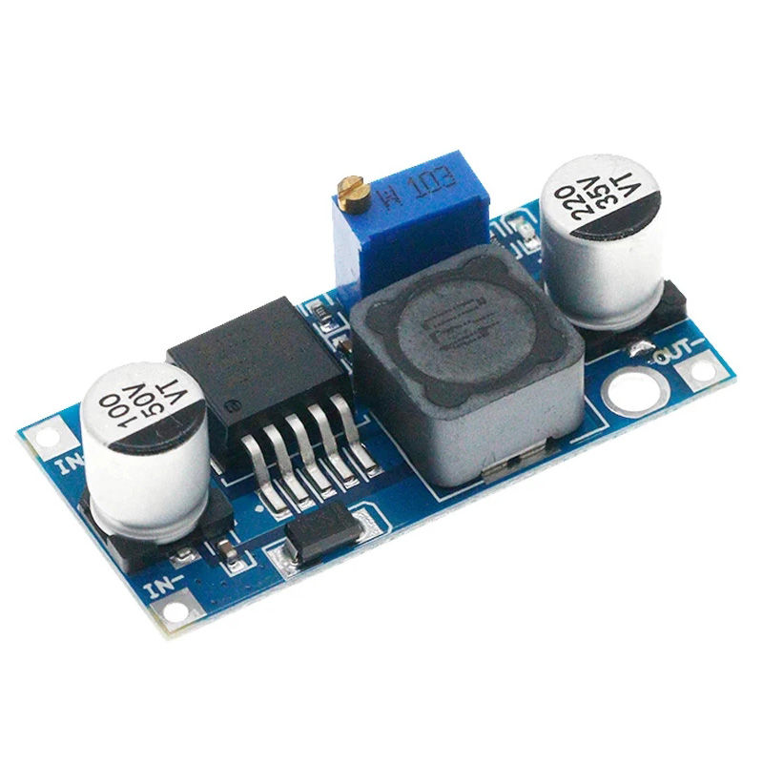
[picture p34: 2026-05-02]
ONA_HARD/3d models/dc-dc-lm2596-3a-step-down-converter-module-1.snapshot.5/HW-411.jpg

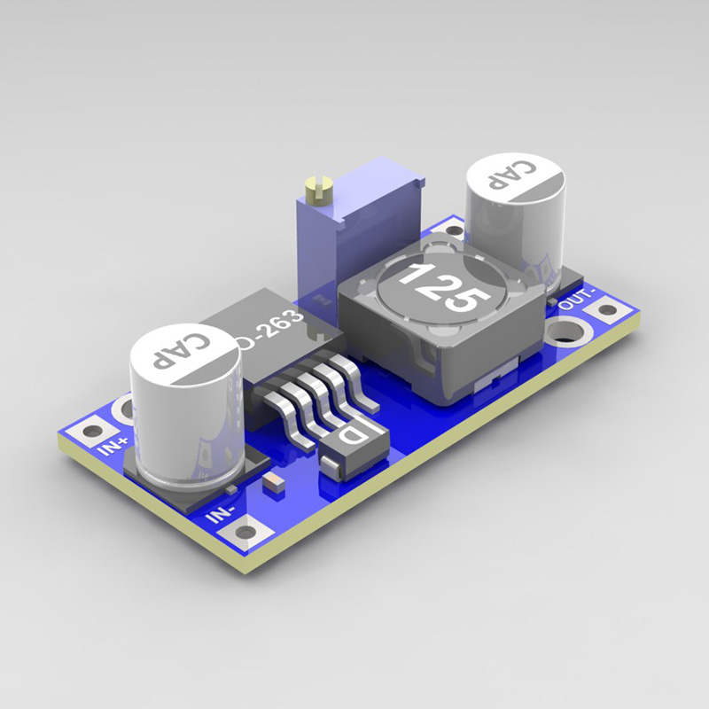
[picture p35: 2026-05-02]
ONA_HARD/3d models/dc-dc-lm2596-3a-step-down-converter-module-1.snapshot.5/HW-411_Render.jpg

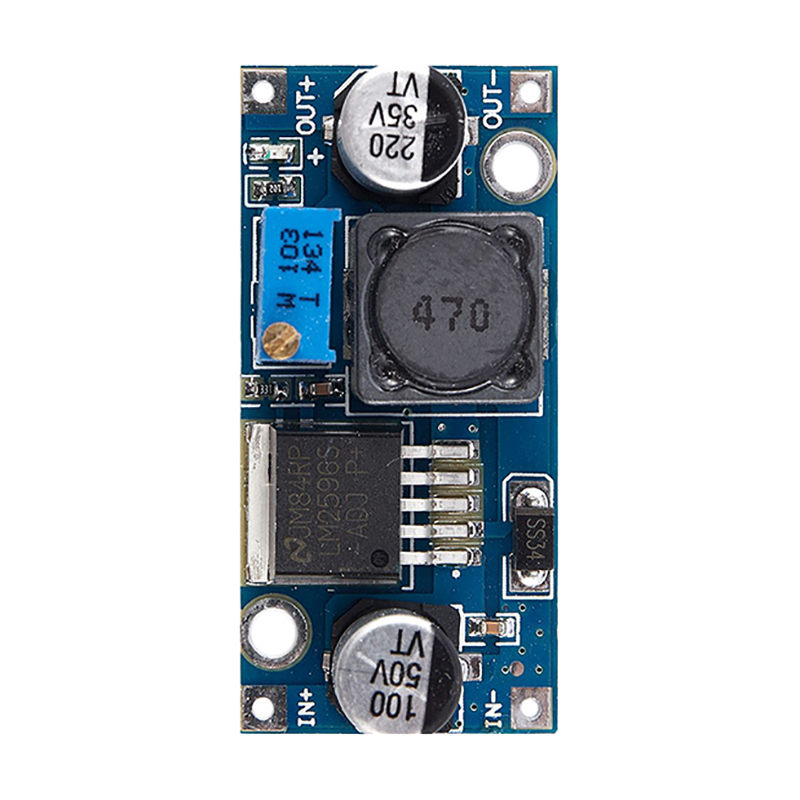
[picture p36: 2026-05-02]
ONA_HARD/3d models/dc-dc-lm2596-3a-step-down-converter-module-1.snapshot.5/HW-411_Top.jpg

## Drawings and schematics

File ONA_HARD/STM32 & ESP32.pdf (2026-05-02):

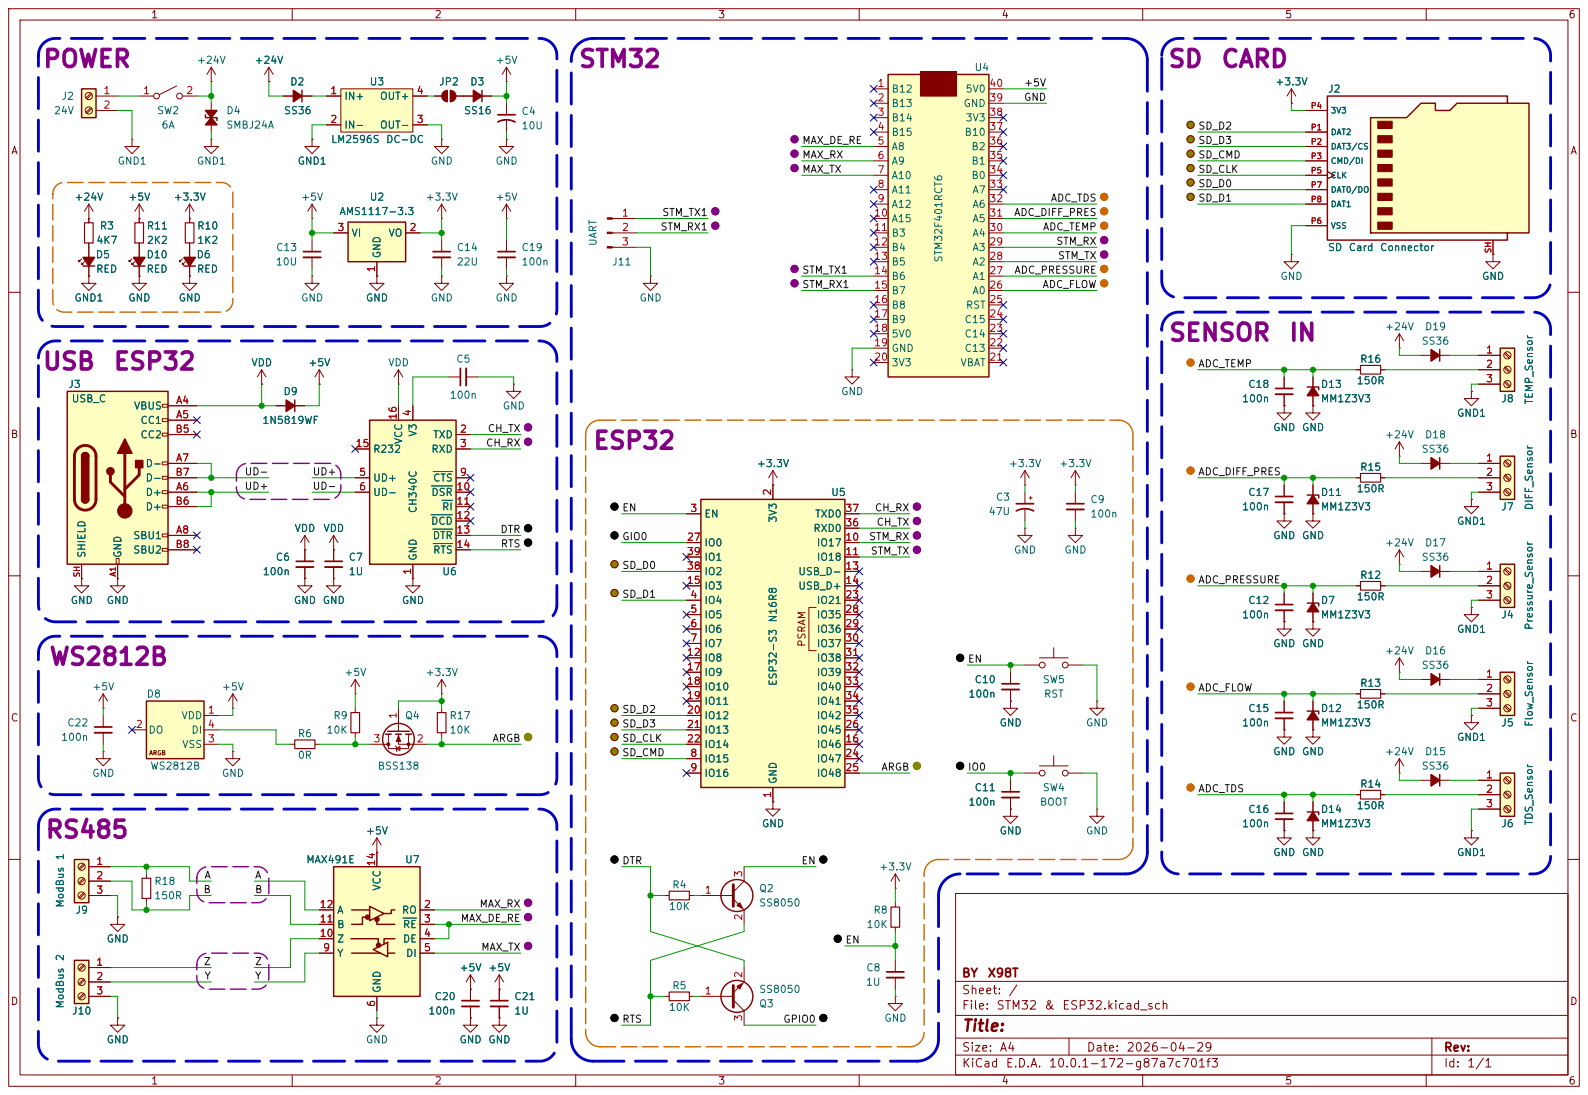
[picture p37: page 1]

4 UD+ 5 UD- 6 CTS 9 DSR 10 RI 11 DCD 12 DTR 13 RTS 14 R232 15 VCC 16 D9

4 UD+ 5 UD- 6 CTS 9 DSR 10 RI 11 DCD 12 DTR 13 RTS 14 R232 15 VCC 16 U6 CH340C

Size: A4 | Rev:
KiCad E.D.A. 10.0.1-172-g87a7c701f3 | Id: 1/1

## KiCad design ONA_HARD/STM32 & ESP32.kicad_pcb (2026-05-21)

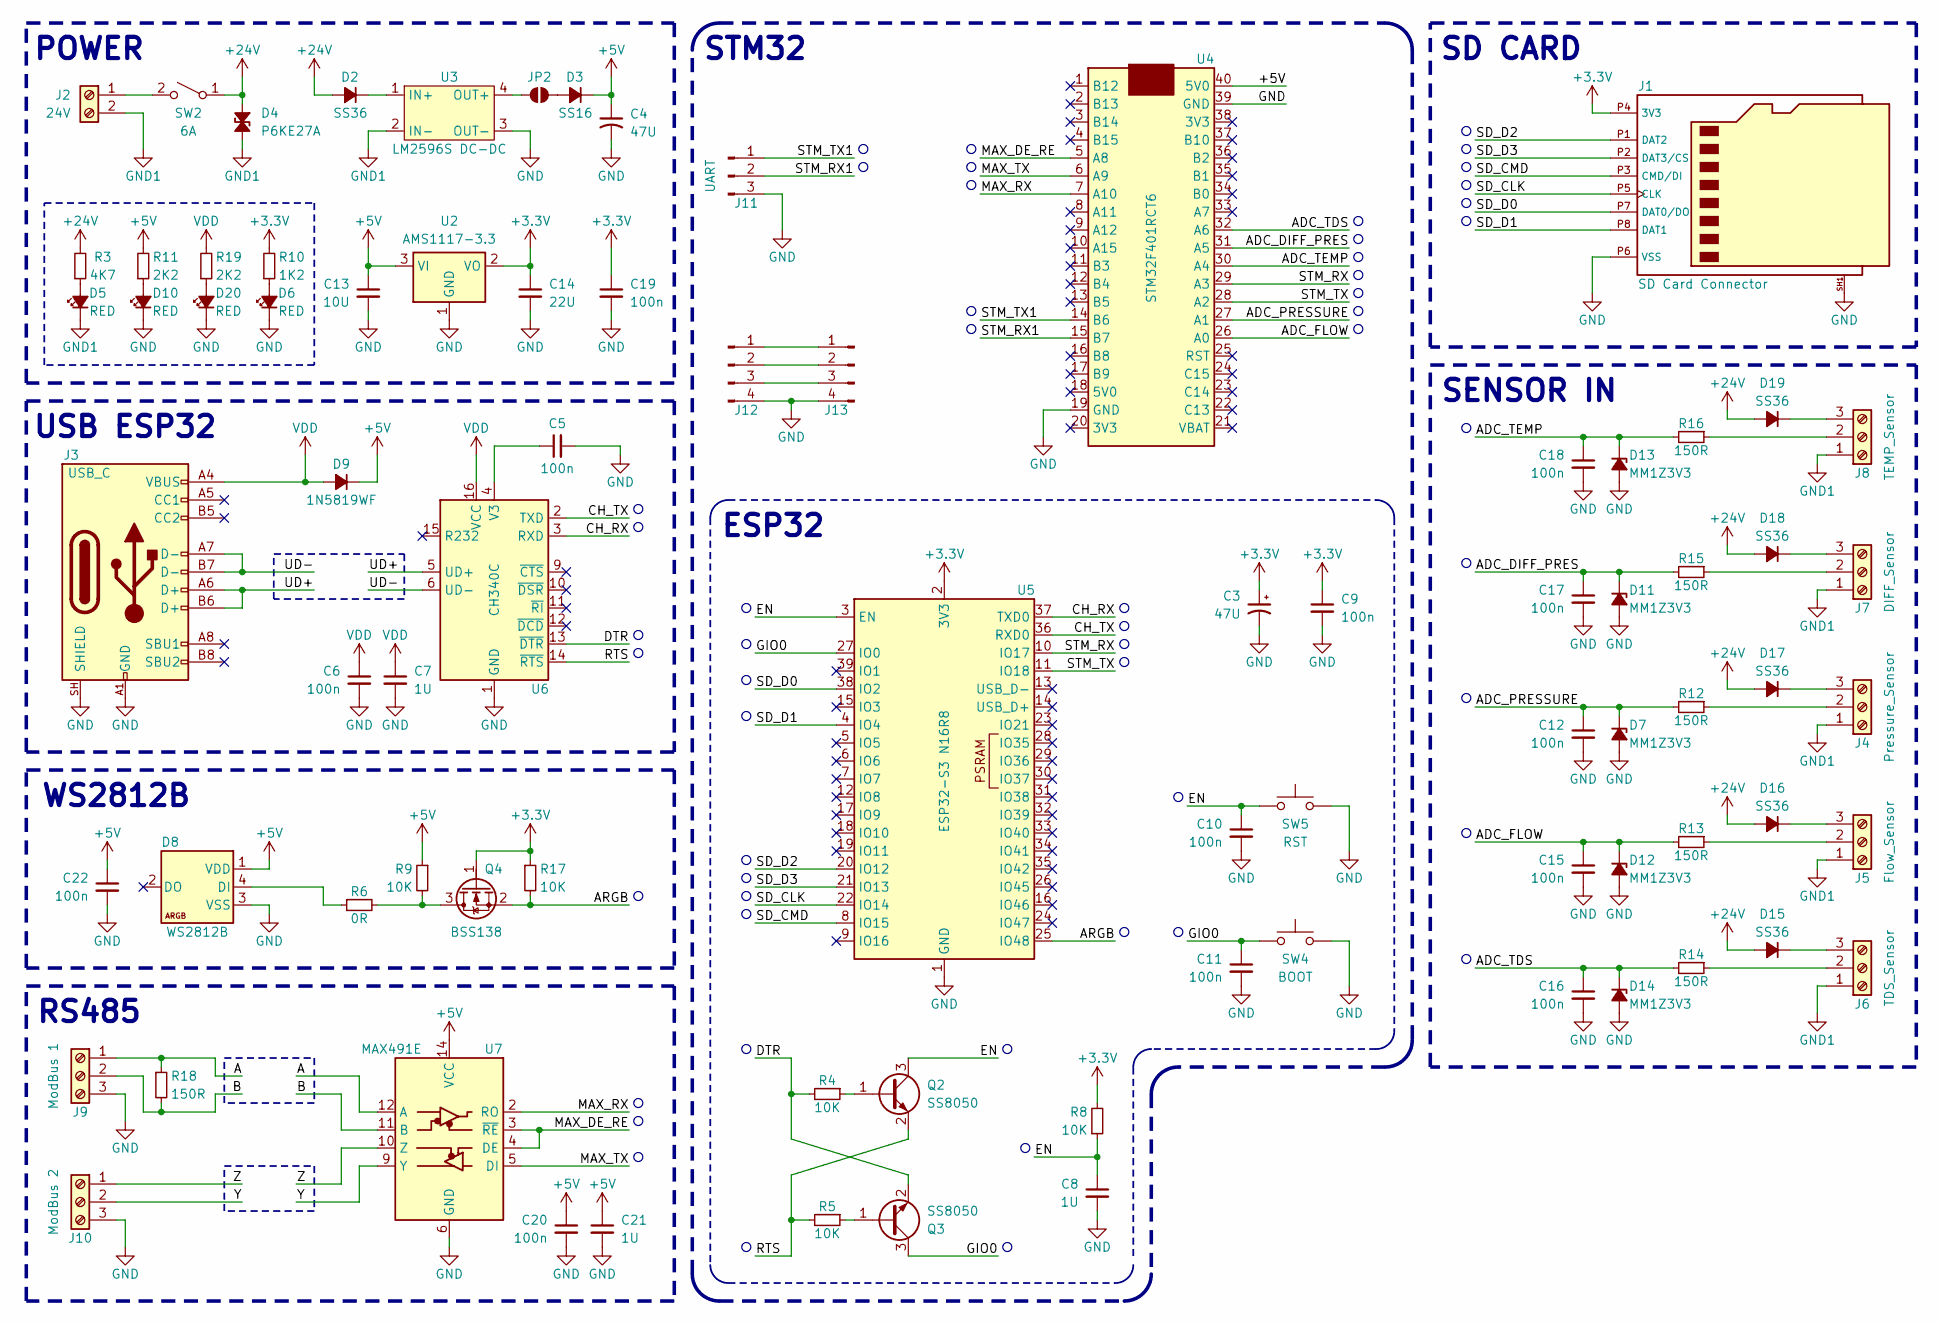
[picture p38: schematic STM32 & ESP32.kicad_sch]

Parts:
C3: 47U; CP_EIA-3528-12_Kemet-T_HandSolder
C4: 47U; CP_Radial_D6.3mm_P2.50mm
C5, C6, C9, C10, C11, C12, C15, C16, C17, C18, C19, C20, C22: 100n; C_0805_2012Metric_Pad1.18x1.45mm_HandSolder
C7, C8, C21: 1U; C_0805_2012Metric_Pad1.18x1.45mm_HandSolder
C13: 10U; C_0805_2012Metric_Pad1.18x1.45mm_HandSolder
C14: 22U; C_0805_2012Metric_Pad1.18x1.45mm_HandSolder
D2, D15, D16, D17, D18, D19: SS36; D_SMA
D3: SS16; D_SMA
D4: P6KE27A; D_DO-15_P12.70mm_Horizontal
D5, D6, D10, D20: RED; LED_0805_2012Metric_Pad1.15x1.40mm_HandSolder
D7, D11, D12, D13, D14: MM1Z3V3; D_SOD-123
D8: WS2812B; LED_WS2812B-Mini_PLCC4_3.5x3.5mm
D9: 1N5819WF; D_SOD-123F
J1: SD Card Connector; SD Card Connector GCT_MEM2075
J2: 24V; Pluggable Terminal 2P P5.08mm
J3: USB_C; USB_C_Receptacle_G-Switch_GT-USB-7010ASV
J4: Pressure_Sensor; Pluggable Terminal 3P P5.08mm
J5: Flow_Sensor; Pluggable Terminal 3P P5.08mm
J6: TDS_Sensor; Pluggable Terminal 3P P5.08mm
J7: DIFF_Sensor; Pluggable Terminal 3P P5.08mm
J8: TEMP_Sensor; Pluggable Terminal 3P P5.08mm
J9: ModBus 1; Pluggable Terminal 3P P5.08mm
J10: ModBus 2; Pluggable Terminal 3P P5.08mm
J11: UART; PinHeader_1x03_P2.54mm_Vertical
J12: Conn_01x04_Pin; PinHeader_1x04_P2.54mm_Vertical
J13: PinHeader_1x04_P2.54mm_Vertical
JP2: SolderJumper_2_Open; SolderJumper-2_P1.3mm_Open_TrianglePad1.0x1.5mm
Q2, Q3: SS8050; SOT-23
Q4: BSS138; SOT-23
R3: 4K7; R_0805_2012Metric_Pad1.20x1.40mm_HandSolder
R4, R5, R8, R9, R17: 10K; R_0805_2012Metric_Pad1.20x1.40mm_HandSolder
R6: 0R; SolderJumper-2_P1.3mm_Open_TrianglePad1.0x1.5mm
R10: 1K2; R_0805_2012Metric_Pad1.20x1.40mm_HandSolder
R11, R19: 2K2; R_0805_2012Metric_Pad1.20x1.40mm_HandSolder
R12, R13, R14, R15, R16, R18: 150R; R_0805_2012Metric_Pad1.20x1.40mm_HandSolder
SW2: 6A; SolderWire-0.5sqmm_1x02_P4.8mm_D0.9mm_OD2.3mm
SW4: BOOT; SW_SPST_PTS647_Sx50
SW5: RST; SW_SPST_PTS647_Sx50
U2: AMS1117-3.3; SOT-223-3_TabPin2
U3: LM2596S DC-DC; LM2596S DC-DC Converter 3A
U4: STM32F401RCT6; Black Pill STM32F401RCT6
U5: ESP32-S3 N16R8; ESP32-S3-WROOM-1
U6: CH340C; SOIC-16_3.9x9.9mm_P1.27mm
U7: MAX491E; SOIC-14_3.9x8.7mm_P1.27mm

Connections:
+3.3V: C3.1, C9.1, C14.1, C19.1, J1.P4 (3V3), Q4.1 (G), R8.2, R10.2, R17.1, U2.2 (VO), U5.2 (3V3)
+5V: C4.1, C13.1, C20.1, C21.1, C22.1, D3.1 (K), D8.1 (VDD), D9.1 (K), R9.1, R11.2, U2.3 (VI), U4.40 (5V0), U7.14 (VCC)
+24V: D2.2 (A), D4.1 (A1), D15.2 (A), D16.2 (A), D17.2 (A), D18.2 (A), D19.2 (A), R3.2, SW2.1 (A)
/A: J9.1, R18.1, U7.12 (A)
/ADC_DIFF_PRES: C17.1, D11.1 (K), R15.2, U4.31 (A5)
/ADC_FLOW: C15.1, D12.1 (K), R13.2, U4.26 (A0)
/ADC_PRESSURE: C12.1, D7.1 (K), R12.2, U4.27 (A1)
/ADC_TDS: C16.1, D14.1 (K), R14.2, U4.32 (A6)
/ADC_TEMP: C18.1, D13.1 (K), R16.2, U4.30 (A4)
/ARGB: Q4.2 (S), R17.2, U5.25 (IO48)
/B: J9.2, R18.2, U7.11 (B)
/CH_RX: U5.37 (TXD0), U6.3 (RXD)
/CH_TX: U5.36 (RXD0), U6.2 (TXD)
/DTR: Q3.2 (E), R4.2, U6.13 (~DTR)
/EN: C8.1, C10.1, Q2.3 (C), R8.1, SW5.2, U5.3 (EN)
/GIO0: C11.1, Q3.3 (C), SW4.2, U5.27 (IO0)
/MAX_DE_RE: U4.5 (A8), U7.3 (~RE), U7.4 (DE)
/MAX_RX: U4.7 (A10), U7.2 (RO)
/MAX_TX: U4.6 (A9), U7.5 (DI)
/RTS: Q2.2 (E), R5.2, U6.14 (~RTS)
/SD_CLK: J1.P5 (CLK), U5.22 (IO14)
/SD_CMD: J1.P3 (CMD/DI), U5.8 (IO15)
/SD_D0: J1.P7 (DAT0/DO), U5.38 (IO2)
/SD_D1: J1.P8 (DAT1), U5.4 (IO4)
/SD_D2: J1.P1 (DAT2), U5.20 (IO12)
/SD_D3: J1.P2 (DAT3/CS), U5.21 (IO13)
/STM_RX: U4.29 (A3), U5.10 (IO17)
/STM_RX1: J11.2, U4.15 (B7)
/STM_TX: U4.28 (A2), U5.11 (IO18)
/STM_TX1: J11.1, U4.14 (B6)
/UD+: J3.A6 (D+), J3.B6 (D+), U6.5 (UD+)
/UD-: J3.A7 (D-), J3.B7 (D-), U6.6 (UD-)
/Y: J10.2, U7.9 (Y)
/Z: J10.1, U7.10 (Z)
GND: C3.2, C4.2, C5.2, C6.2, C7.2, C8.2, C9.2, C10.2, C11.2, C12.2, C13.2, C14.2, C15.2, C16.2, C17.2, C18.2, C19.2, C20.2, C21.2, C22.2, D6.1 (K), D7.2 (A), D8.3 (VSS), D10.1 (K), D11.2 (A), D12.2 (A), D13.2 (A), D14.2 (A), D20.1 (K), J1.P6 (VSS), J1.SH1, J1.SH2 (SHIELD), J1.SH3 (SHIELD), J1.SH4 (SHIELD), J3.A1 (GND), J3.A12 (GND), J3.B1 (GND), J3.B12 (GND), J3.SH (SHIELD), J9.3, J10.3, J11.3, J12.4, J13.4, SW4.1, SW5.1, U2.1 (GND), U3.3 (OUT-), U4.19 (GND), U4.39 (GND), U5.1 (GND), U5.40 (GND), U5.41 (GND), U6.1 (GND), U7.6 (GND), U7.7 (GND)
GND1: D4.2 (A2), D5.1 (K), J2.2, J4.1, J5.1, J6.1, J7.1, J8.1, U3.2 (IN-)
unnamed: D2.1 (K), U3.1 (IN+)
unnamed: D3.2 (A), JP2.2 (B)
unnamed: D5.2 (A), R3.1
unnamed: D6.2 (A), R10.1
unnamed: D8.4 (DI), R6.1
unnamed: D10.2 (A), R11.1
unnamed: D15.1 (K), J6.3
unnamed: D16.1 (K), J5.3
unnamed: D17.1 (K), J4.3
unnamed: D18.1 (K), J7.3
unnamed: D19.1 (K), J8.3
unnamed: D20.2 (A), R19.1
unnamed: J2.1, SW2.2 (B)
unnamed: J4.2, R12.1
unnamed: J5.2, R13.1
unnamed: J6.2, R14.1
unnamed: J7.2, R15.1
unnamed: J8.2, R16.1
unnamed: J12.1, J13.1
unnamed: J12.2, J13.2
unnamed: J12.3, J13.3
unnamed: JP2.1 (A), U3.4 (OUT+)
unnamed: Q2.1 (B), R4.1
unnamed: Q3.1 (B), R5.1
unnamed: Q4.3 (D), R6.2, R9.2
unnamed: C5.1, U6.4 (V3)
VDD: C6.1, C7.1, D9.2 (A), J3.A4 (VBUS), J3.A9 (VBUS), J3.B4 (VBUS), J3.B9 (VBUS), R19.2, U6.16 (VCC)

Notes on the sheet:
SD CARD
USB ESP32
POWER
SENSOR IN
ESP32
RS485
STM32
WS2812B

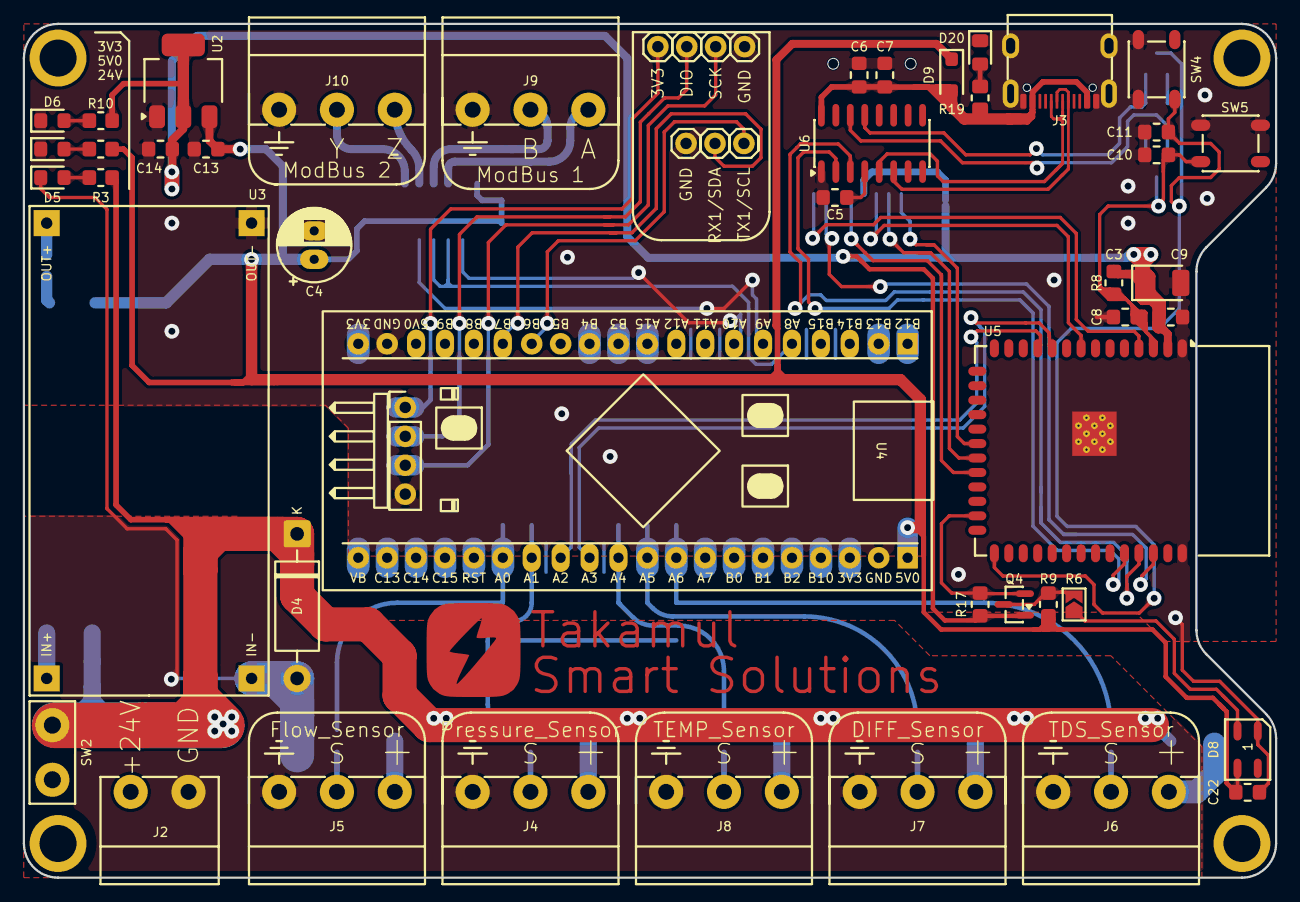
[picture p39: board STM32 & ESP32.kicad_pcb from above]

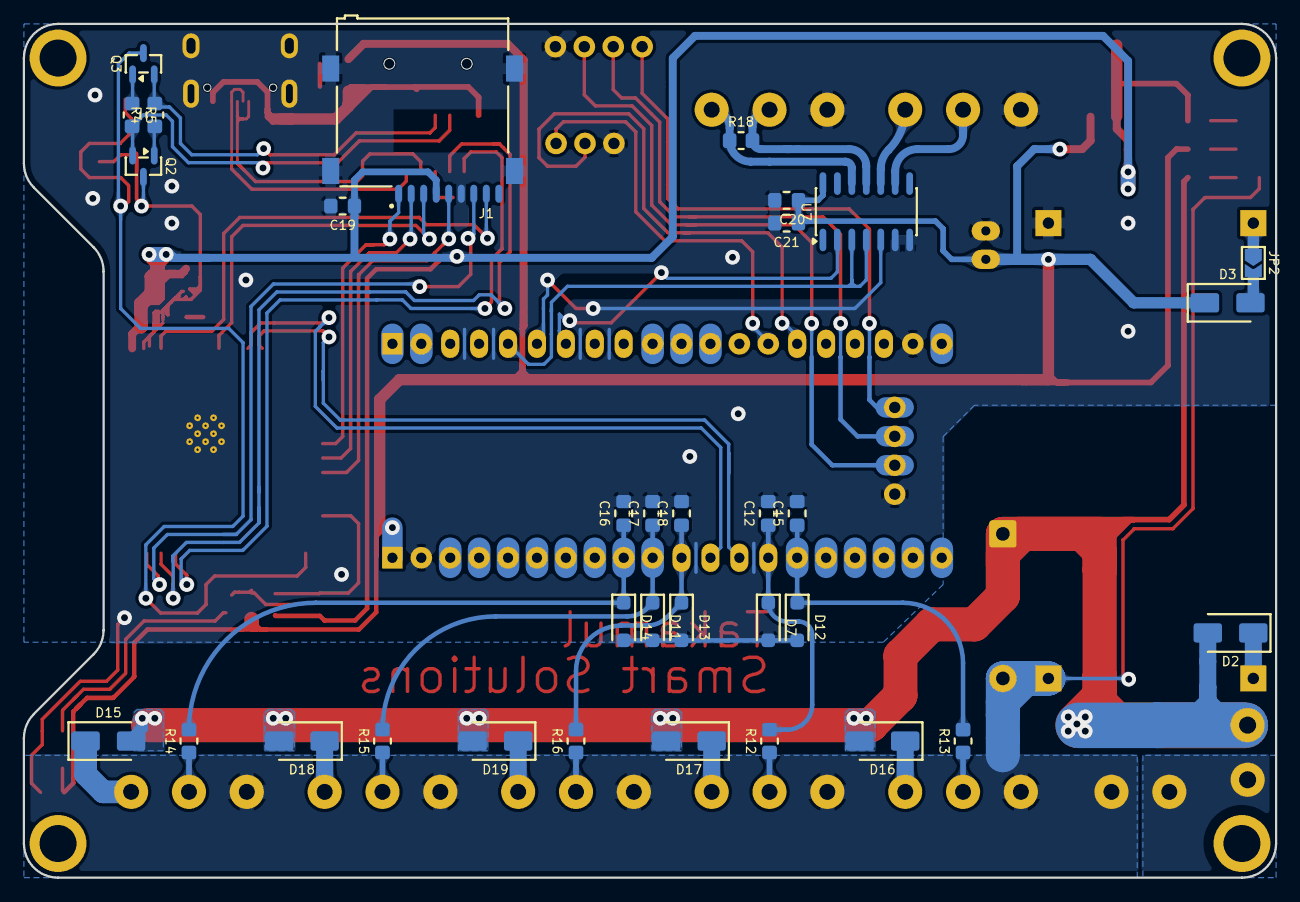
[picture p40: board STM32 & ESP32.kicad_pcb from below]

Board: 2 copper layers, 110.0 x 75.0 mm, 81 parts (33 on the bottom side), 63 nets.

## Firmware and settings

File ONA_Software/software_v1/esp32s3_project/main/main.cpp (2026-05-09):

/**
 * ============================================================================
 *  Takamul SCADA — ESP32 Firmware
 *  Target  : ESP32-S3 N16R8 + ESP-IDF v5.x  (C++17)
 *
 *  Boot flow (every cycle after deep sleep):
 *   1. SleepManager::init() + checkWakeupReason()
 *   2. NVS init
 *   3. WiFi connect (from credentials saved in NVS)
 *      first boot only -> AP mode + captive portal
 *   4. UART init (STM32 bridge)
 *   5. Supabase init
 *   6. Get sensor frame from STM32
 *   7. Check thresholds -> if anomaly, shorten next sleep
 *   8. Upload telemetry to Supabase
 *   9. Get controls (pump/speed) + send to STM32
 *  10. Check OTA
 *  11. SleepManager::prepareAndSleep() -> deep sleep (5 minutes)
 *      [SLEEP DISABLED] -> continuous loop mode
 *
 *  Wakeup sources:
 *   - Timer (5 min)         -> Normal state
 *   - EXT1 GPIO IO21 HIGH   -> STM32 raised alert (sensor fault / pump fault)
 *   - (force_wakeup flag)   -> Website requested urgent wakeup -> sleep 30s only
 *
 *  Data flow:
 *   STM32 -> UART -> UartBridge -> TelemetryManager -> Supabase (telemetry)
 *   Supabase (controls) -> TelemetryManager -> UartBridge -> STM32
 * ============================================================================
 */

#include "main.h"
#include "esp_log.h"
#include "esp_system.h"

static const char* TAG = "main";

// ─── Helper: read MAC as "AA:BB:CC:DD:EE:FF" ─────────────────────────────────
static std::string readMacString() {
    uint8_t mac[6] = {};
    esp_read_mac(mac, ESP_MAC_WIFI_STA);
    char buf[18];
    snprintf(buf, sizeof(buf), "%02X:%02X:%02X:%02X:%02X:%02X",
             mac[0], mac[1], mac[2], mac[3], mac[4], mac[5]);
    return std::string(buf);
}

// ─── Helper: connect WiFi (STA or AP fallback) ───────────────────────────────
static bool connectWifi(Takamul::WifiManager& wifi, Takamul::NVSManager& nvs) {
    std::string nvs_ssid, nvs_pass;

    Takamul::NVSHandle handle("wifi_config", NVS_READONLY);
    bool has_creds = handle.isValid()
                  && handle.getString("ssid",     nvs_ssid) == ESP_OK
                  && handle.getString("password", nvs_pass) == ESP_OK
                  && !nvs_ssid.empty();

    if (!has_creds) {
        // first boot or credentials cleared -> provisioning
        ESP_LOGI(TAG, "No WiFi credentials -> provisioning mode");

        // do not sleep in provisioning mode
        Takamul::SleepManager::getInstance().disableSleep();

        wifi.startAP();
        Takamul::WebServer::getInstance().start();

        while (!wifi.waitForStaIp(pdMS_TO_TICKS(1000))) {
            ESP_LOGD(TAG, "  ...waiting for IP");
        }

        Takamul::WebServer::getInstance().stop();
        ESP_LOGI(TAG, "Provisioning complete");

        // keep sleep disabled — app_main will enter loop mode
        return true;
    }

    // STA mode
    ESP_LOGI(TAG, "Connecting to: %s", nvs_ssid.c_str());
    wifi.startSTA(nvs_ssid, nvs_pass);

    if (wifi.waitForStaIp(pdMS_TO_TICKS(15000))) {
        return true;
    }

    // connection failed -> AP fallback
    ESP_LOGW(TAG, "Failed to connect '%s' — AP fallback", nvs_ssid.c_str());
    Takamul::SleepManager::getInstance().disableSleep();
    wifi.startAP();
    Takamul::WebServer::getInstance().start();

    while (!wifi.waitForStaIp(pdMS_TO_TICKS(1000))) {
        ESP_LOGD(TAG, "  ...waiting for IP (fallback)");
    }

    Takamul::WebServer::getInstance().stop();
    return true;
}

// ─── app_main ─────────────────────────────────────────────────────────────────

extern "C" void app_main(void) {

    // ══════════════════════════════════════════════════════════════════════════
    //  STEP 1 — Sleep Manager
    // ══════════════════════════════════════════════════════════════════════════

    auto& sleepMgr = Takamul::SleepManager::getInstance();
    sleepMgr.init();
    sleepMgr.disableSleep();   // ← SLEEP DISABLED: device stays awake permanently
    Takamul::WakeupReason reason = sleepMgr.checkWakeupReason();

    ESP_LOGI(TAG, "========================================");
    ESP_LOGI(TAG, "  Takamul SCADA — ESP32-S3 Firmware    ");
    ESP_LOGI(TAG, "  Wakeup: %s",
             reason == Takamul::WakeupReason::Timer     ? "TIMER" :
             reason == Takamul::WakeupReason::GpioAlert ? "GPIO ALERT" :
             reason == Takamul::WakeupReason::FirstBoot ? "FIRST BOOT" : "UNKNOWN");
    ESP_LOGI(TAG, "========================================");

    // ══════════════════════════════════════════════════════════════════════════
    //  STEP 2 — NVS
    // ══════════════════════════════════════════════════════════════════════════

    auto& nvsMgr = Takamul::NVSManager::getInstance();
    nvsMgr.init();

    // ══════════════════════════════════════════════════════════════════════════
    //  STEP 3 — WiFi
    // ══════════════════════════════════════════════════════════════════════════

    auto& wifiMgr = Takamul::WifiManager::getInstance();
    wifiMgr.init();
    connectWifi(wifiMgr, nvsMgr);
    ESP_LOGI(TAG, "WiFi connected ✓");

    // ══════════════════════════════════════════════════════════════════════════
    //  STEP 4 — Device Identity
    // ══════════════════════════════════════════════════════════════════════════

    std::string device_id = readMacString();
    ESP_LOGI(TAG, "Device ID: %s", device_id.c_str());

    // ══════════════════════════════════════════════════════════════════════════
    //  STEP 5 — Supabase
    // ══════════════════════════════════════════════════════════════════════════

    auto& supabase = Takamul::SupabaseClient::getInstance();
    supabase.init(CONFIG_TAKAMUL_SUPABASE_URL, CONFIG_TAKAMUL_SUPABASE_KEY);

    // ══════════════════════════════════════════════════════════════════════════
    //  STEP 6 — UART Bridge (ESP32 <-> STM32)
    // ══════════════════════════════════════════════════════════════════════════

    auto& uart = Takamul::UartBridge::getInstance();
    uart.init(UART_STM32_PORT, UART_STM32_RX_PIN, UART_STM32_TX_PIN, UART_STM32_BAUD);

    // ══════════════════════════════════════════════════════════════════════════
    //  STEP 7 — Telemetry Manager (continuous mode)
    // ══════════════════════════════════════════════════════════════════════════

    auto& telem = Takamul::TelemetryManager::getInstance();
    telem.init(device_id);

    // Start UART — frames will be forwarded to TelemetryManager continuously
    uart.start([&telem](const Takamul::SensorFrame& f) {
        telem.onSensorFrame(f);
    });

    // Start telemetry tasks (upload + poll loops)
    telem.start();

    ESP_LOGI(TAG, "Sleep disabled — running in continuous mode");
    ESP_LOGI(TAG, "Running in continuous mode — tasks started");
    // ── Heartbeat loop ────────────────────────────────────────────────────────
    while (true) {
        vTaskDelay(pdMS_TO_TICKS(30000));
        ESP_LOGI(TAG, "♥ Heartbeat — continuous mode");
    }
}

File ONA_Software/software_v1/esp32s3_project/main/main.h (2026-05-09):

#ifndef MAIN_H_
#define MAIN_H_

#include "sdkconfig.h"
#include "esp_mac.h"
#include "freertos/FreeRTOS.h"
#include "freertos/task.h"
#include "driver/gpio.h"
#include "driver/uart.h"

// ─── Custom drivers ───────────────────────────────────────────────────────────
#include "inc/NVSManager.h"
#include "inc/WifiManager.h"
#include "inc/WebServer.h"
#include "inc/SupabaseClient.h"
#include "inc/UartBridge.h"
#include "inc/TelemetryManager.h"
#include "inc/Sleepmanager.h"       

// ─── Supabase config ──────────────────────────────────────────────────────────
#ifndef CONFIG_TAKAMUL_SUPABASE_URL
#define CONFIG_TAKAMUL_SUPABASE_URL \
    "https://xfcicrtmyvpgirwvnqfh.supabase.co"
#endif

#ifndef CONFIG_TAKAMUL_SUPABASE_KEY
#define CONFIG_TAKAMUL_SUPABASE_KEY \
    "eyJhbGciOiJIUzI1NiIsInR5cCI6IkpXVCJ9." \
    "eyJpc3MiOiJzdXBhYmFzZSIsInJlZiI6InhmY2ljcnRteXZwZ2lyd3ZucWZoIiwicm9sZSI6ImFub24iLCJpYXQiOjE3Nzc0MjIzNzYsImV4cCI6MjA5Mjk5ODM3Nn0." \
    "W6NkexIqULpwRa-3G4x_C6bAmaZXgRm7xXxRypibJ7A"
#endif

// ─── UART config (ESP32 <-> STM32) ─────────────────────────────────────────────
// From the schematic:
//   STM_TX (STM32 TX) -> ESP32 IO18 (RX)
//   STM_RX (STM32 RX) -> ESP32 IO17 (TX)
#define UART_STM32_PORT    UART_NUM_2
#define UART_STM32_RX_PIN  GPIO_NUM_18   // ESP32 RX <- STM32 TX
#define UART_STM32_TX_PIN  GPIO_NUM_17   // ESP32 TX -> STM32 RX
#define UART_STM32_BAUD    115200

// ─── Deep Sleep Config ────────────────────────────────────────────────────────

// Normal sleep duration - 5 minutes
#define SLEEP_NORMAL_MINUTES    5

// Sleep duration when there is an anomaly - 60 seconds
#define SLEEP_ANOMALY_SECONDS   60

// Sleep duration when force_wakeup from website - 30 seconds
#define SLEEP_FORCE_SECONDS     30

// FIX: Changed from GPIO_NUM_38 to GPIO_NUM_21.
// ESP32-S3 EXT1 wakeup only works with RTC GPIOs (IO0–IO21).
// IO38 is NOT an RTC GPIO — log was showing: "E sleep: Not an RTC IO: GPIO38"
// Reconnect the STM32 alert wire from IO38 to IO21 on the PCB.
#define STM32_ALERT_GPIO_PIN    GPIO_NUM_21

// ─── Sensor Thresholds ────────────────────────────────────────────────────────

#define THRESHOLD_TDS_MAX       1000.0f   // ppm  - above this -> polluted water
#define THRESHOLD_PRESSURE_MAX  6.0f      // bar  - above this -> high pressure
#define THRESHOLD_PRESSURE_MIN  0.5f      // bar  - below this -> low pressure / leak
#define THRESHOLD_FLOW_MIN      1.0f      // L/min - below this with pump on -> issue
#define THRESHOLD_TEMP_MAX      45.0f     // °C   - above this -> high temperature

// Sudden change is considered an anomaly
#define THRESHOLD_TDS_CHANGE_PCT  0.20f   // 20% change in TDS
#define THRESHOLD_PRESSURE_JUMP   1.0f    // bar  - sudden jump in pressure

// ─── Stack Size ───────────────────────────────────────────────────────────────
// FIX: The main task stack was overflowing (8KB needed for WiFi + HTTP + strings).
// Set CONFIG_ESP_MAIN_TASK_STACK_SIZE=8192 in sdkconfig or menuconfig:
//   idf.py menuconfig -> Component config -> ESP System Settings
//                     -> Main task stack size -> 8192
// The default (3584) is too small for this application.

#endif // MAIN_H_

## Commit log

2026-03-25 Auther: Ziad, Breif: add hardware
    [Controller.kicad_sch, Flow Sensor.kicad_sch, ModBus.kicad_sch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]
2026-05-02 add software
    [First Debug.cfg, sensors_data.csv]
2026-05-02 stm32 files
    [modbus_mapping_controll Debug.cfg, modbus_v2 Debug.cfg]
2026-05-02 Remove .history folder and add to gitignore
    [BOM.xlsx, antenna.obj, antenna.stl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]
2026-05-02 chore: remove .history folders and add to gitignore
    [BOM.xlsx, Controller.kicad_sch, Flow Sensor.kicad_sch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]
2026-05-02 init product
    [BOM.xlsx, Controller.kicad_sch, Flow Sensor.kicad_sch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]
2026-05-02 add hard v1
    [10P.STEP, 11P.STEP, 12P.STEP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]
2026-05-09 add 3d model
    [Back cover.SLDPRT, Back cover.STL, Back.SLDPRT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]
2026-05-21 add docs
    [STM32 & ESP32.kicad_pcb, STM32 & ESP32.kicad_sch]

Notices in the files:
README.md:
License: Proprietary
